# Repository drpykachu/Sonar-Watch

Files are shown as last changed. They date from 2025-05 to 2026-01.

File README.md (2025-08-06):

# Sonar Watch

### Hello all! 

### This project is inspired by something that I wanted to buy, but could not find online - so I decided to make it.

<div align="center">
  Demo
</div>

### When the button is pressed, the watch sends out a "ping" to find the location of the hour (inner radial dot) and minute (outer radial dot), thus telling the time.

<div align="center">
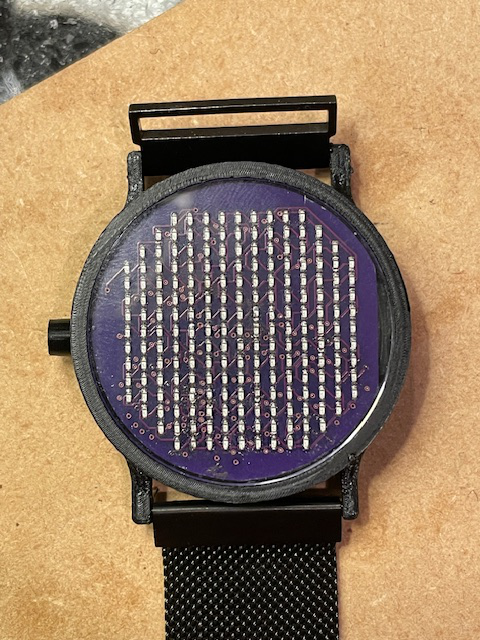
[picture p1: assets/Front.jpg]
Front
  
  <br/>
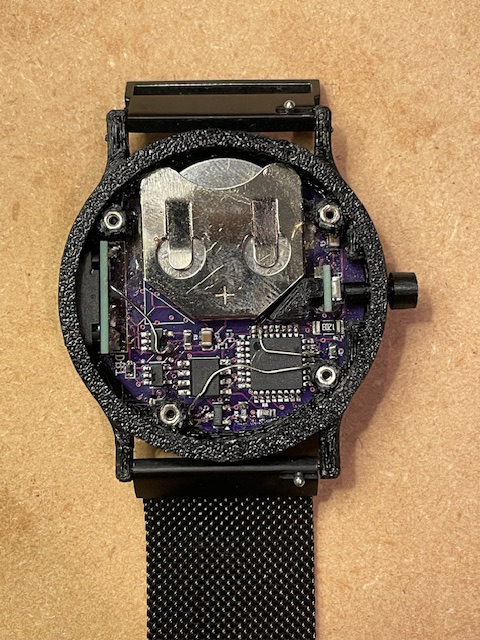
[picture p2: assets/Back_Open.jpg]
Back (open)
  
  <br/>
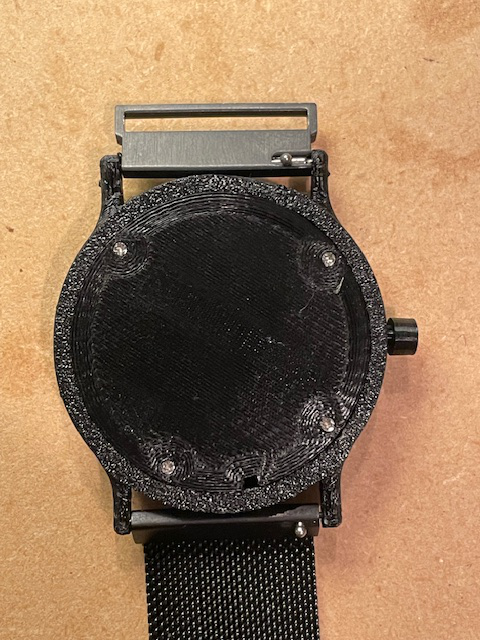
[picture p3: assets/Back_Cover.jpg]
Back (closed)
  
  <br/>
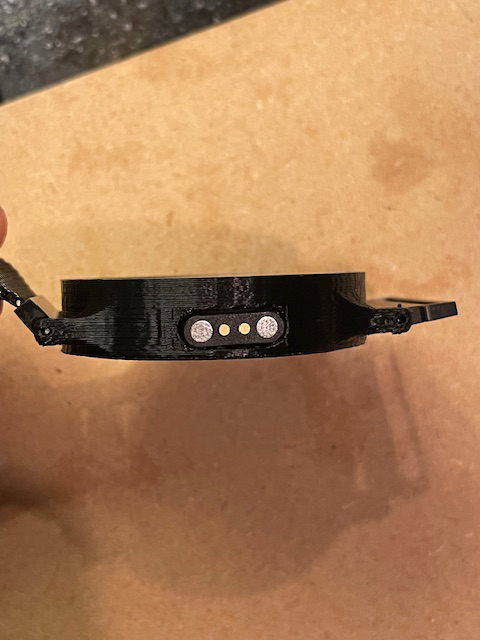
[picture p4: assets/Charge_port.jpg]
Magnetic Charging Port
  
</div>

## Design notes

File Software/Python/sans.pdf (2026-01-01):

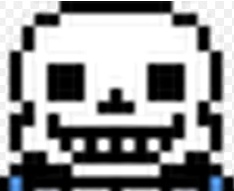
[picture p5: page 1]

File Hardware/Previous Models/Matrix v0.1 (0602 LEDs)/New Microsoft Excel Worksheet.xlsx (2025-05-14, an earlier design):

Column1 | A | B | C | D | E | F
1.1 | LOW | HIGH | INPUT | INPUT | INPUT | INPUT
1.2 | LOW | INPUT | HIGH | INPUT | INPUT | INPUT
1.3 | HIGH | INPUT | LOW | INPUT | INPUT | INPUT
1.4 | INPUT | INPUT | LOW | INPUT | HIGH | INPUT
1.5 | INPUT | INPUT | HIGH | INPUT | LOW | INPUT
2.1 | INPUT | LOW | HIGH | INPUT | INPUT | INPUT
2.2 | INPUT | HIGH | LOW | INPUT | INPUT | INPUT
2.3 | LOW | INPUT | INPUT | INPUT | HIGH | INPUT
2.4 | HIGH | INPUT | INPUT | INPUT | LOW | INPUT
2.5 | INPUT | INPUT | LOW | INPUT | INPUT | HIGH
3.1 | INPUT | INPUT | LOW | HIGH | INPUT | INPUT
3.2 | INPUT | LOW | INPUT | INPUT | HIGH | INPUT
3.3 | INPUT | HIGH | INPUT | INPUT | LOW | INPUT
3.4 | LOW | INPUT | INPUT | INPUT | INPUT | HIGH
3.5 | HIGH | INPUT | INPUT | INPUT | INPUT | LOW
4.1 | INPUT | INPUT | INPUT | LOW | HIGH | INPUT
4.2 | INPUT | INPUT | INPUT | HIGH | LOW | INPUT
4.3 | INPUT | LOW | INPUT | INPUT | INPUT | HIGH
4.4 | INPUT | HIGH | INPUT | INPUT | INPUT | LOW
4.5 | LOW | INPUT | INPUT | HIGH | INPUT | INPUT
5.1 | INPUT | INPUT | INPUT | INPUT | LOW | HIGH
5.2 | INPUT | INPUT | INPUT | LOW | INPUT | HIGH
5.3 | INPUT | INPUT | INPUT | HIGH | INPUT | LOW
5.4 | INPUT | LOW | INPUT | HIGH | INPUT | INPUT
5.5 | INPUT | HIGH | INPUT | LOW | INPUT | INPUT

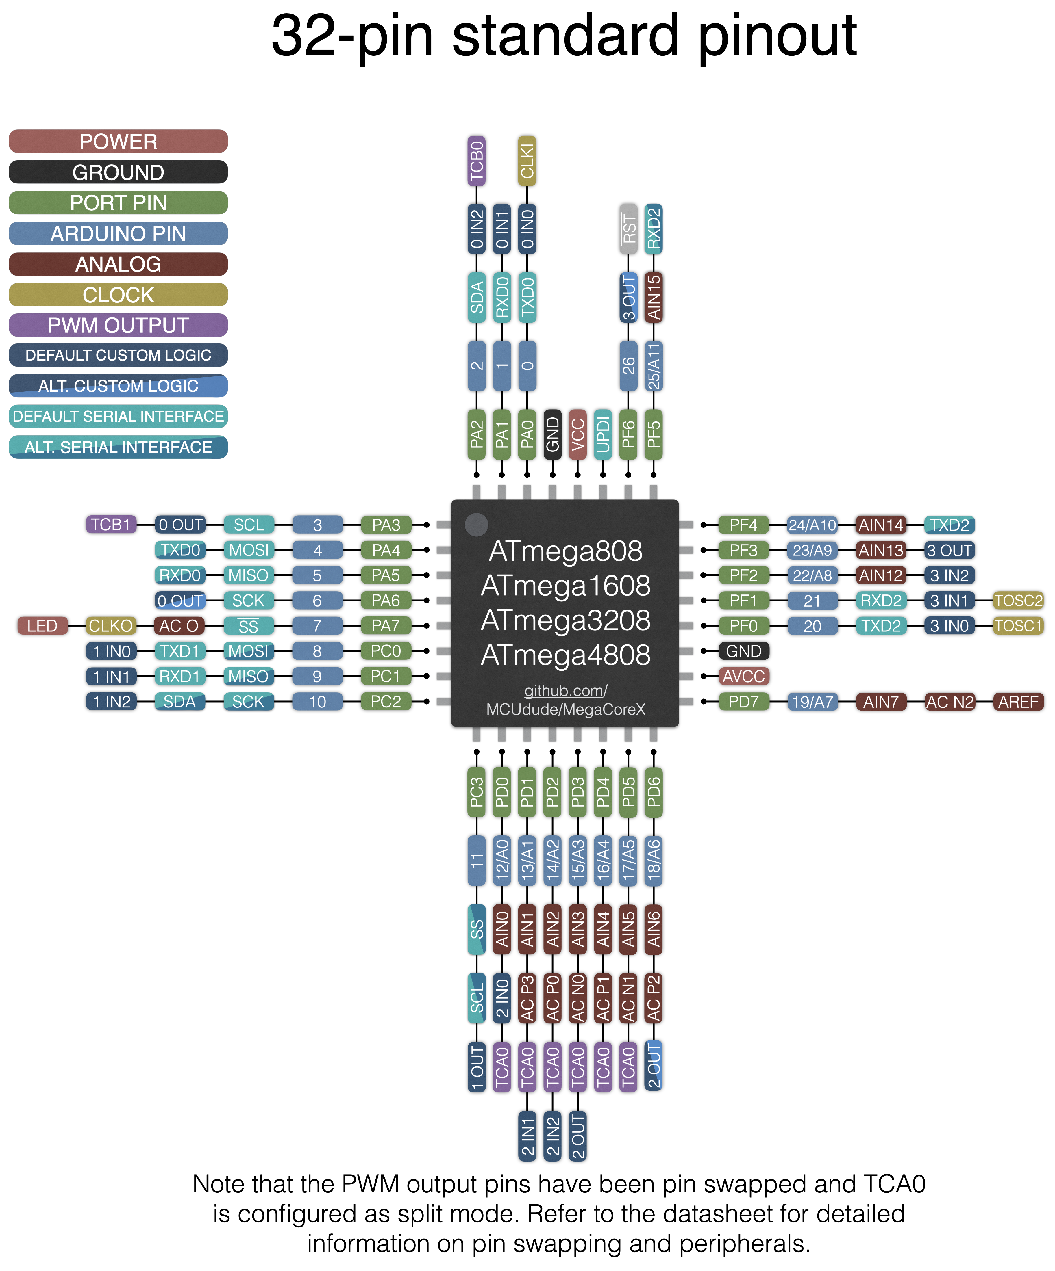
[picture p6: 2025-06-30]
Hardware/Complete v3.0/68747470733a2f2f692e696d6775722e636f6d2f32596c6d4538702e706e67.png

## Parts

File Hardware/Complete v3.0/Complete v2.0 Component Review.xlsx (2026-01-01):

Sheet: Connections
Reference: | POGO1
Component: | 2x1 Pogo Connector
Function: | USB Charging
Pin # | Pin Function | Connects to Component | At Pin | Reviewed? | Notes
1 | USB_+ | CHG1 | 4 | Yes
1 | USB_+ | DB1 | A | Yes
2 | USB_- | GNDREF | -- | Yes
3 | UPDI | 27 | 27 | Yes
4 | NC | -- | -- | Yes
Reference: | CHG1
Component: | MCP73832T-2ACI_OT
Function: | Battery Charger
Pin # | Pin Function | Connects to Component | At Pin | Reviewed? | Notes
1 | STAT | R3 | 1 | Yes
1 | STAT | U2 | PF4 | Yes
2 | VSS | GNDREF | -- | Yes
3 | VBAT | C2 | 1 | Yes
3 | VBAT | BT1 | P | Yes
3 | VBAT | U1 | 1 | Yes
3 | VBAT | R5 | 1 | Yes
4 | VDD | POGO1 | 1 | Yes
4 | VDD | DB1 | A | Yes
5 | PROG | R1 | 1 | Yes
Reference: | U1
Component: | Voltage Regulator
Function: | regualtes votlage to 3.3V
Pin # | Pin Function | Connects to Component | At Pin | Reviewed? | Notes
1 | IN | CHG1 | VBAT | Yes
1 | IN | BT1 | P | Yes
1 | IN | R5 | 1 | Yes
2 | VSS | GNDREF | -- | Yes
3 | EN | DB1 | C | Yes
3 | EN | DB2 | C | Yes
4 | NC | -- | -- | Yes
5 | OUT | C1 | 1 | Yes
5 | OUT | U3 | VBAT | Yes
5 | OUT | R7 | 2 | Yes
5 | OUT | R8 | 2 | Yes
5 | OUT | U2 | 28 | Yes
5 | OUT | U2 | 18 | Yes
5 | OUT | BB_B1 | 1 | Yes
5 | OUT | R3 | 2 | Yes
Reference: | U2
Component: | ATMEGA4808-AU
Function: | Controller
Pin # | Pin Function | Connects to Component | At Pin | Reviewed? | Notes
1 | PA3 | U3 | SCL | Yes
2 | PA4 | LED | A | Yes
3 | PA5 | LED | B | Yes
4 | PA6 | LED | C | Yes
5 | PA7 | LED | D | Yes
6 | PC0 | LED | E | Yes
7 | PC1 | LED | F | Yes
8 | PC2 | LED | G | Yes
9 | PC3 | LED | H | Yes
10 | PD0 | LED | I | Yes
11 | PD1 | LED | J | Yes
12 | PD2 | LED | K | Yes
13 | PD3 | LED | L | Yes
14 | PD4 | LED | M | Yes
15 | PD5 | LED | N | Yes
16 | PD6 | LED | O | Yes
17 | PD7 | LED | P | Yes
18 | AVDD | C1 | 1 | Yes
18 | AVDD | U3 | VBAT | Yes
18 | AVDD | R7 | 2 | Yes
18 | AVDD | R8 | 2 | Yes
18 | AVDD | U2 | 28 | Yes
18 | AVDD | BB_B1 | 1 | Yes
18 | AVDD | R3 | 2 | Yes
18 | AVDD | U1 | 5 | Yes
19 | GND | GNDREF | -- | Yes
20 | PF0 | NC | -- | Yes
21 | PF1 | NC | -- | Yes
22 | PF2 | NC | -- | Yes
23 | PF3 | U3 | VCC | Yes
24
25
26

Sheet: Parts
Index | Item | Added? | Acquired | Board Count | Purchase Amount | Unit Price | Max Price | Link
1 | GRM21BC81E106ME51K | Yes | Yes | 0 | 0 | $0.24 | $0.00 | https://www.digikey.com/en/products/detail/murata-electronics/GRM21BC81E106ME51K/10694904
2 | RN73H1JTTD5052F50 | Yes | Yes | 0 | 0 | $0.21 | $0.00 | https://www.digikey.co.nz/en/products/detail/koa-speer-electronics-inc/RN73H1JTTD5052F50/10689137
3 | MCP73832T-2ACI_OT | Yes | Yes | 1 | 15 | $0.76 | $11.40 | https://www.digikey.com/en/products/detail/microchip-technology/MCP73832T-2ACI-OT/1223142
4 | LIR2032 | Yes | Yes | 0 | 0 | $1.33 | $0.00 | https://www.amazon.com/EEMB-LIR2032-Rechargeable-Batteries-Controllers/dp/B07MHXSM8R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
5 | TPS7A0230PDBVR | Yes | Yes | 0 | 0 | $1.30 | $0.00 | https://www.digikey.com/en/products/detail/texas-instruments/TPS7A0230PDBVR/12165118
6 | BAS3010A03WE6327HTSA1 | Yes | Yes | 0 | 0 | $0.36 | $0.00 | https://www.digikey.com/en/products/detail/infineon-technologies/BAS3010A03WE6327HTSA1/1280885
8 | B3U-1100P | Yes | Yes | 0 | 0 | $0.57 | $0.00 | https://www.digikey.com/en/products/detail/omron-electronics-inc-emc-div/B3U-1100P/1534339
9 | STM32G431KBT6 (LQFP32) |  | Yes | 0 | 0 | $4.87 | $0.00 | https://estore.st.com/en/stm32g431kbt6-cpn.html
10 | RC1206FR-07120KL | Yes | Yes | 0 | 0 | $0.10 | $0.00 | https://www.digikey.com/en/products/detail/yageo/RC1206FR-07120KL/728524
11 | RMCF0603FT300K | Yes | Yes | 0 | 0 | $0.10 | $0.00 | https://www.digikey.com/en/products/detail/stackpole-electronics-inc/RMCF0603FT300K/1760826
12 | 1N4148WT | Yes | Yes | 0 | 0 | $0.10 | $0.00 | https://www.digikey.com/en/products/detail/onsemi/1N4148WT/1954014
13 | BAT-HLD-003-SMT | Yes | Yes | 1 | 15 | $0.28 | $4.20 | https://www.digikey.com/en/products/detail/te-connectivity-linx/BAT-HLD-003-SMT/14301785
14 | Pogo | Yes | Yes | 1 | 15 | $5.00 | $74.92 | https://www.amazon.com/dp/B0CSX6ZQ1H?ref_=ppx_hzsearch_conn_dt_b_fed_asin_title_1
15 | RC1005F103CS | Yes | Yes | 1 | 15 | $0.10 | $1.50 | https://www.digikey.com/en/products/detail/samsung-electro-mechanics/RC1005F103CS/3903439
16 | DS3231MZ/V+ | Yes | Yes | 1 | 3 | $11.41 | $34.23 | https://www.digikey.com/en/products/detail/analog-devices-inc-maxim-integrated/DS3231MZ-V/3133910
17 | IRLML6402TRPBF | Yes | Yes | 1 | 15 | $0.40 | $6.00 | https://www.digikey.com/en/products/detail/infineon-technologies/IRLML6402TRPBF/811437
18 | LEDS | Yes | Yes | 201 | 500 | $33.34 | $33.34 | https://www.digikey.com/en/products/detail/venkel/CTL0402FGR1T-CT/21528282
18 | RC0201FR-074K7L | Yes | Yes | 2 | 30 | $0.10 | $3.00 | https://www.digikey.com/en/products/detail/yageo/RC0201FR-074K7L/1948894
19 | ATMEGA4808-AU | Yes | Yes | 1 | 10 | $1.57 | $15.70 | https://www.digikey.com/en/products/detail/microchip-technology/ATMEGA4808-AU/10444933?gad_source=1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
20 | SI2301DS | Yes | Yes | 1 | 100 | $6.95 | $6.95 | https://www.amazon.com/dp/B08RHQGB8F?ref=ppx_yo2ov_dt_b_fed_asin_title

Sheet: Math
Programming Resistor |  |  |  |  |  | LIR2032: |  |  |  |  | MCP73832T-2ACI_OT
Item | Value | Units
R_Prog | 50.5 | kOhm
I_Reg | 19.8019802 | mA | beneath the 35mA max charge current
Capacity | 40 | mAh
time to full | 2.02 | hours
Voltage Ladder Part 1 - finding Resistances at Max charge
Item | Value | Units
Current | 0.0100 | mA |  | 4000
R_TOT | 420 | kOhms
V1 | 4.2 | V
V2 | 3 | V
GROUND | 0 | V
R1 | 120 | kOhms
R2 | 300 | kOhms
Voltage Ladder Part 2 - Finding voltages at Min charge
Item | Value | Units
Current | 0.007142857143 | mA
R_TOT | 420 | kOhms
R1 | 120 | kOhms
R2 | 300 | kOhms
V1 | 3 | V
V2 | 2.142857143 | V
GROUND | 0 | V
Voltage Ladder Part 3 - Finding voltages at random charge
Item | Value | Units
Current | 0.007380952381 | mA
R_TOT | 420 | kOhms
R1 | 120 | kOhms
R2 | 300 | kOhms |  |  |  |  | Voltage - capacity chart
V1 | 3.1 | V
GROUND | 0 | V
V2 | 2.214285714 | V
Voltage Ladder Part 4 - Finding minum voltage to portect battery
Item | Value | Units
Current | 0.007619047619 | mA |  |  | Raw data |  |  | Needed data
R_TOT | 420 | kOhms |  |  | V | Cap |  | adjsuted volts | Scaled volts | inverse charge
R1 | 120 | kOhms |  |  | 4.14 | 0.29 |  | 4.2 | 3.000 | 100
R2 | 300 | kOhms |  |  | 4.10 | 2.43 |  | 4.14 | 2.960 | 99
V1 | 3.2 | V |  |  | 4.05 | 4.56 |  | 4.10 | 2.928 | 97.57338873
GROUND | 0 | V |  |  | 4.02 | 7.01 |  | 4.05 | 2.896 | 95.43544664
V2 | 2.285714286 | V |  |  | 3.97 | 10.52 |  | 4.02 | 2.873 | 92.9900383
 |  |  |  |  | 3.93 | 13.73 |  | 3.97 | 2.835 | 89.47543515
 |  |  |  |  | 3.86 | 17.86 |  | 3.93 | 2.806 | 86.26561294
 |  |  |  |  | 3.83 | 21.68 |  | 3.86 | 2.759 | 82.14010525
 |  |  |  |  | 3.79 | 26.88 |  | 3.83 | 2.733 | 78.31758831
 |  |  |  |  | 3.75 | 31.93 |  | 3.79 | 2.710 | 73.11706766
 |  |  |  |  | 3.73 | 36.82 |  | 3.75 | 2.677 | 68.07095145
 |  |  |  |  | 3.71 | 42.64 |  | 3.73 | 2.663 | 63.17521175
 |  |  |  |  | 3.70 | 49.37 |  | 3.71 | 2.648 | 57.36110127
 |  |  |  |  | 3.67 | 57.18 |  | 3.70 | 2.640 | 50.62772492
 |  |  |  |  | 3.67 | 64.52 |  | 3.67 | 2.620 | 42.8247062
 |  |  |  |  | 3.66 | 71.56 |  | 3.67 | 2.620 | 35.47774003
 |  |  |  |  | 3.65 | 79.67 |  | 3.66 | 2.617 | 28.43734499
 |  |  |  |  | 3.61 | 84.87 |  | 3.65 | 2.608 | 20.32641248
 |  |  |  |  | 3.57 | 89.00 |  | 3.61 | 2.579 | 15.12678693
 |  |  |  |  | 3.52 | 93.74 |  | 3.57 | 2.547 | 10.9990415
 |  |  |  |  | 3.39 | 97.09 |  | 3.52 | 2.512 | 6.259496433
 |  |  |  |  | 3.27 | 99.99 |  | 3.39 | 2.422 | 2.906010957
 |  |  |  |  | 3.13 | 102.73 |  | 3.20 | 2.286 | 0.01126331925
 |  |  |  |  | 2.99 | 105.16

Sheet: LED_Pins
Index | 0 | 1 | 2 | 3 | 4 | 5 | 6 | 7 | 8 | 9 | 10 | 11 | 12 | 13 | 14 | 15
Pin
 | A | B | C | D | E | F | G | H | I | J | K | L | M | N | O | P
LED\NET | 1 | 2 | 3 | 4 | 5 | 6 | 7 | 8 | 9 | 10 | 11 | 12 | 13 | 14 | 15 | 16
D1 | LOW |  |  |  | HIGH
D2 | HIGH |  |  |  | LOW
D3 |  |  |  |  | LOW |  | HIGH
D4 |  |  |  |  | HIGH |  | LOW
D5 |  |  |  |  |  |  | LOW |  | HIGH
D6 |  |  |  |  |  |  | HIGH |  | LOW
D7 |  |  |  |  |  |  |  |  | LOW |  | HIGH
D8 |  |  |  |  |  |  |  |  | HIGH |  | LOW
D9 |  |  |  |  |  |  |  |  |  |  | LOW |  | HIGH
D10 |  | LOW |  |  | HIGH
D11 |  | HIGH |  |  | LOW
D12 | LOW |  |  |  |  |  | HIGH
D13 | HIGH |  |  |  |  |  | LOW
D14 |  |  |  |  | LOW |  |  |  | HIGH
D15 |  |  |  |  | HIGH |  |  |  | LOW
D16 |  |  |  |  |  |  | LOW |  |  |  | HIGH
D17 |  |  |  |  |  |  | HIGH |  |  |  | LOW
D18 |  |  |  |  |  |  |  |  | LOW |  |  |  | HIGH
D19 |  |  |  |  |  |  |  |  | HIGH |  |  |  | LOW
D20 |  |  |  |  |  |  |  |  |  |  | LOW |  |  | HIGH
D21 |  |  | LOW |  | HIGH
D22 |  |  | HIGH |  | LOW
D23 |  | LOW |  |  |  |  | HIGH
D24 |  | HIGH |  |  |  |  | LOW
D25 | LOW |  |  |  |  |  |  |  | HIGH
D26 | HIGH |  |  |  |  |  |  |  | LOW
D27 |  |  |  |  | LOW |  |  |  |  |  | HIGH
D28 |  |  |  |  | HIGH |  |  |  |  |  | LOW
D29 |  |  |  |  |  |  | LOW |  |  |  |  |  | HIGH
D30 |  |  |  |  |  |  | HIGH |  |  |  |  |  | LOW
D31 |  |  |  |  |  |  |  |  | LOW |  |  |  |  | HIGH
D32 |  |  |  |  |  |  |  |  | HIGH |  |  |  |  | LOW
D33 |  |  |  |  |  |  |  |  |  |  | LOW |  |  |  | HIGH
D34 |  |  |  | LOW | HIGH
D35 |  |  |  | HIGH | LOW
D36 |  |  | LOW |  |  |  | HIGH
D37 |  |  | HIGH |  |  |  | LOW
D38 |  | LOW |  |  |  |  |  |  | HIGH
D39 |  | HIGH |  |  |  |  |  |  | LOW
D40 | LOW |  |  |  |  |  |  |  |  |  | HIGH
D41 | HIGH |  |  |  |  |  |  |  |  |  | LOW
D42 |  |  |  |  | LOW |  |  |  |  |  |  |  | HIGH
D43 |  |  |  |  | HIGH |  |  |  |  |  |  |  | LOW
D44 |  |  |  |  |  |  | LOW |  |  |  |  |  |  | HIGH
D45 |  |  |  |  |  |  | HIGH |  |  |  |  |  |  | LOW
D46 |  |  |  |  |  |  |  |  | LOW |  |  |  |  |  | HIGH
D47 |  |  |  |  |  |  |  |  | HIGH |  |  |  |  |  | LOW
D48 |  |  |  |  |  |  |  |  |  |  | LOW |  |  |  |  | HIGH
D49 |  |  |  |  | LOW | HIGH
D50 |  |  |  | LOW |  |  | HIGH
D51 |  |  |  | HIGH |  |  | LOW
D52 |  |  | LOW |  |  |  |  |  | HIGH
D53 |  |  | HIGH |  |  |  |  |  | LOW
D54 |  | LOW |  |  |  |  |  |  |  |  | HIGH
D55 |  | HIGH |  |  |  |  |  |  |  |  | LOW
D56 | LOW |  |  |  |  |  |  |  |  |  |  |  | HIGH
D57 | HIGH |  |  |  |  |  |  |  |  |  |  |  | LOW
D58 |  |  |  |  | LOW |  |  |  |  |  |  |  |  | HIGH
D59 |  |  |  |  | HIGH |  |  |  |  |  |  |  |  | LOW
D60 |  |  |  |  |  |  | LOW |  |  |  |  |  |  |  | HIGH
D61 |  |  |  |  |  |  | HIGH |  |  |  |  |  |  |  | LOW
D62 |  |  |  |  |  |  |  |  | LOW |  |  |  |  |  |  | HIGH
D63 |  |  |  |  |  |  |  |  | HIGH |  |  |  |  |  |  | LOW
D64 |  |  |  |  |  | LOW | HIGH
D65 |  |  |  |  |  | HIGH | LOW
D66 |  |  |  | LOW |  |  |  |  | HIGH
D67 |  |  |  | HIGH |  |  |  |  | LOW
D68 |  |  | LOW |  |  |  |  |  |  |  | HIGH
D69 |  |  | HIGH |  |  |  |  |  |  |  | LOW
D70 |  | LOW |  |  |  |  |  |  |  |  |  |  | HIGH
D71 |  | HIGH |  |  |  |  |  |  |  |  |  |  | LOW
D72 | LOW |  |  |  |  |  |  |  |  |  |  |  |  | HIGH
D73 | HIGH |  |  |  |  |  |  |  |  |  |  |  |  | LOW
D74 |  |  |  |  | LOW |  |  |  |  |  |  |  |  |  | HIGH
D75 |  |  |  |  | HIGH |  |  |  |  |  |  |  |  |  | LOW
D76 |  |  |  |  |  |  | LOW |  |  |  |  |  |  |  |  | HIGH
D77 |  |  |  |  |  |  | HIGH |  |  |  |  |  |  |  |  | LOW
D78 |  |  |  |  |  |  |  |  | LOW |  |  | HIGH
D79 |  |  |  |  |  |  | LOW | HIGH
D80 |  |  |  |  |  | LOW |  |  | HIGH
D81 |  |  |  |  |  | HIGH |  |  | LOW
D82 |  |  |  | LOW |  |  |  |  |  |  | HIGH
D83 |  |  |  | HIGH |  |  |  |  |  |  | LOW
D84 |  |  | LOW |  |  |  |  |  |  |  |  |  | HIGH
D85 |  |  | HIGH |  |  |  |  |  |  |  |  |  | LOW
D86 |  | LOW |  |  |  |  |  |  |  |  |  |  |  | HIGH
D87 |  | HIGH |  |  |  |  |  |  |  |  |  |  |  | LOW
D88 | LOW |  |  |  |  |  |  |  |  |  |  |  |  |  | HIGH
D89 | HIGH |  |  |  |  |  |  |  |  |  |  |  |  |  | LOW
D90 |  |  |  |  | LOW |  |  |  |  |  |  |  |  |  |  | HIGH
D91 |  |  |  |  | HIGH |  |  |  |  |  |  |  |  |  |  | LOW
D92 |  |  |  |  |  |  | LOW |  |  |  |  | HIGH
D93 |  |  |  |  |  |  | HIGH |  |  |  |  | LOW
D94 |  |  |  |  |  |  |  | LOW | HIGH
D95 |  |  |  |  |  |  |  | HIGH | LOW
D96 |  |  |  |  |  | LOW |  |  |  |  | HIGH
D97 |  |  |  |  |  | HIGH |  |  |  |  | LOW
D98 |  |  |  | LOW |  |  |  |  |  |  |  |  | HIGH
D99 |  |  |  | HIGH |  |  |  |  |  |  |  |  | LOW
D100 |  |  | LOW |  |  |  |  |  |  |  |  |  |  | HIGH
D101 |  |  | HIGH |  |  |  |  |  |  |  |  |  |  | LOW
D102 |  | LOW |  |  |  |  |  |  |  |  |  |  |  |  | HIGH
D103 |  | HIGH |  |  |  |  |  |  |  |  |  |  |  |  | LOW
D104 | LOW |  |  |  |  |  |  |  |  |  |  |  |  |  |  | HIGH
D105 | HIGH |  |  |  |  |  |  |  |  |  |  |  |  |  |  | LOW
D106 |  |  |  |  | LOW |  |  |  |  |  |  | HIGH
D107 |  |  |  |  | HIGH |  |  |  |  |  |  | LOW
D108 |  |  |  |  |  |  | LOW |  |  | HIGH
D109 |  |  |  |  |  |  |  |  | LOW | HIGH
D110 |  |  |  |  |  |  |  | LOW |  |  | HIGH
D111 |  |  |  |  |  |  |  | HIGH |  |  | LOW
D112 |  |  |  |  |  | LOW |  |  |  |  |  |  | HIGH
D113 |  |  |  |  |  | HIGH |  |  |  |  |  |  | LOW
D114 |  |  |  | LOW |  |  |  |  |  |  |  |  |  | HIGH
D115 |  |  |  | HIGH |  |  |  |  |  |  |  |  |  | LOW
D116 |  |  | LOW |  |  |  |  |  |  |  |  |  |  |  | HIGH
D117 |  |  | HIGH |  |  |  |  |  |  |  |  |  |  |  | LOW
D118 |  | LOW |  |  |  |  |  |  |  |  |  |  |  |  |  | HIGH
D119 |  | HIGH |  |  |  |  |  |  |  |  |  |  |  |  |  | LOW
D120 | LOW |  |  |  |  |  |  |  |  |  |  | HIGH
D121 | HIGH |  |  |  |  |  |  |  |  |  |  | LOW
D122 |  |  |  |  | LOW |  |  |  |  | HIGH
D123 |  |  |  |  | HIGH |  |  |  |  | LOW
D124 |  |  |  |  |  |  |  |  |  | LOW | HIGH
D125 |  |  |  |  |  |  |  |  |  | HIGH | LOW
D126 |  |  |  |  |  |  |  | LOW |  |  |  |  | HIGH
D127 |  |  |  |  |  |  |  | HIGH |  |  |  |  | LOW
D128 |  |  |  |  |  | LOW |  |  |  |  |  |  |  | HIGH
D129 |  |  |  |  |  | HIGH |  |  |  |  |  |  |  | LOW
D130 |  |  |  | LOW |  |  |  |  |  |  |  |  |  |  | HIGH
D131 |  |  |  | HIGH |  |  |  |  |  |  |  |  |  |  | LOW
D132 |  |  | LOW |  |  |  |  |  |  |  |  |  |  |  |  | HIGH
D133 |  |  | HIGH |  |  |  |  |  |  |  |  |  |  |  |  | LOW
D134 |  | LOW |  |  |  |  |  |  |  |  |  | HIGH
D135 |  | HIGH |  |  |  |  |  |  |  |  |  | LOW
D136 | LOW |  |  |  |  |  |  |  |  | HIGH
D137 | HIGH |  |  |  |  |  |  |  |  | LOW
D138 |  |  |  |  | LOW |  |  | HIGH
D139 |  |  |  |  |  |  |  |  |  |  | LOW | HIGH
D140 |  |  |  |  |  |  |  |  |  | LOW |  |  | HIGH
D141 |  |  |  |  |  |  |  |  |  | HIGH |  |  | LOW
D142 |  |  |  |  |  |  |  | LOW |  |  |  |  |  | HIGH
D143 |  |  |  |  |  |  |  | HIGH |  |  |  |  |  | LOW
D144 |  |  |  |  |  | LOW |  |  |  |  |  |  |  |  | HIGH
D145 |  |  |  |  |  | HIGH |  |  |  |  |  |  |  |  | LOW
D146 |  |  |  | LOW |  |  |  |  |  |  |  |  |  |  |  | HIGH
D147 |  |  |  | HIGH |  |  |  |  |  |  |  |  |  |  |  | LOW
D148 |  |  | LOW |  |  |  |  |  |  |  |  | HIGH
D149 |  |  | HIGH |  |  |  |  |  |  |  |  | LOW
D150 |  | LOW |  |  |  |  |  |  |  | HIGH
D151 |  | HIGH |  |  |  |  |  |  |  | LOW
D152 | LOW |  |  |  |  |  |  | HIGH
D153 | HIGH |  |  |  |  |  |  | LOW
D154 |  |  |  |  |  |  |  |  |  |  |  | LOW | HIGH
D155 |  |  |  |  |  |  |  |  |  |  |  | HIGH | LOW
D156 |  |  |  |  |  |  |  |  |  | LOW |  |  |  | HIGH
D157 |  |  |  |  |  |  |  |  |  | HIGH |  |  |  | LOW
D158 |  |  |  |  |  |  |  | LOW |  |  |  |  |  |  | HIGH
D159 |  |  |  |  |  |  |  | HIGH |  |  |  |  |  |  | LOW
D160 |  |  |  |  |  | LOW |  |  |  |  |  |  |  |  |  | HIGH
D161 |  |  |  |  |  | HIGH |  |  |  |  |  |  |  |  |  | LOW
D162 |  |  |  | LOW |  |  |  |  |  |  |  | HIGH
D163 |  |  |  | HIGH |  |  |  |  |  |  |  | LOW
D164 |  |  | LOW |  |  |  |  |  |  | HIGH
D165 |  |  | HIGH |  |  |  |  |  |  | LOW
D166 |  | LOW |  |  |  |  |  | HIGH
D167 |  | HIGH |  |  |  |  |  | LOW
D168 | LOW |  |  |  |  | HIGH
D169 |  |  |  |  |  |  |  |  |  |  |  | LOW |  | HIGH
D170 |  |  |  |  |  |  |  |  |  |  |  | HIGH |  | LOW
D171 |  |  |  |  |  |  |  |  |  | LOW |  |  |  |  | HIGH
D172 |  |  |  |  |  |  |  |  |  | HIGH |  |  |  |  | LOW
D173 |  |  |  |  |  |  |  | LOW |  |  |  |  |  |  |  | HIGH
D174 |  |  |  |  |  |  |  | HIGH |  |  |  |  |  |  |  | LOW
D175 |  |  |  |  |  | LOW |  |  |  |  |  | HIGH
D176 |  |  |  |  |  | HIGH |  |  |  |  |  | LOW
D177 |  |  |  | LOW |  |  |  |  |  | HIGH
D178 |  |  |  | HIGH |  |  |  |  |  | LOW
D179 |  |  | LOW |  |  |  |  | HIGH
D180 |  |  | HIGH |  |  |  |  | LOW
D181 |  | LOW |  |  |  | HIGH
D182 |  |  |  |  |  |  |  |  |  |  |  | LOW |  |  | HIGH
D183 |  |  |  |  |  |  |  |  |  |  |  | HIGH |  |  | LOW
D184 |  |  |  |  |  |  |  |  |  | LOW |  |  |  |  |  | HIGH
D185 |  |  |  |  |  |  |  |  |  | HIGH |  |  |  |  |  | LOW
D186 |  |  |  |  |  |  |  | LOW |  |  |  | HIGH
D187 |  |  |  |  |  |  |  | HIGH |  |  |  | LOW
D188 |  |  |  |  |  | LOW |  |  |  | HIGH
D189 |  |  |  |  |  | HIGH |  |  |  | LOW
D190 |  |  |  | LOW |  |  |  | HIGH
D191 |  |  |  | HIGH |  |  |  | LOW
D192 |  |  | LOW |  |  | HIGH
D193 |  |  |  |  |  |  |  |  |  |  |  | LOW |  |  |  | HIGH
D194 |  |  |  |  |  |  |  |  |  |  |  | HIGH |  |  |  | LOW
D195 |  |  |  |  |  |  |  |  |  | LOW |  | HIGH
D196 |  |  |  |  |  |  |  |  |  | HIGH |  | LOW
D197 |  |  |  |  |  |  |  | LOW |  | HIGH
D198 |  |  |  |  |  |  |  | HIGH |  | LOW
D199 |  |  |  |  |  | LOW |  | HIGH
D200 |  |  |  |  |  | HIGH |  | LOW
D201 |  |  |  | LOW |  | HIGH
LOW | 12 | 12 | 12 | 12 | 15 | 10 | 15 | 13 | 15 | 13 | 15 | 13 | 11 | 11 | 11 | 11
HIGH | 11 | 11 | 11 | 11 | 13 | 15 | 13 | 15 | 13 | 15 | 10 | 15 | 12 | 12 | 12 | 12

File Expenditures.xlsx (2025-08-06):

Source | Order Date | Cost | Items | Purpose
PCBWAY | 2025-04-09 | $27.16 | 5x5 board | Testing
Amazon | 2025-04-15 | $39.71 | Hot Plate | Tool
Ebay | 2025-04-22 | $14.09 | LEDS | Testing
Ebay | 2025-04-22 | $30.02 | LEDS | Final
OSH Stencils | 2025-04-27 | $26.22 | Stencil 1 | Testing
STM | 2025-04-29 | $34.24 | Nucleo board | None
SUPPLIER DIRECT | 2025-04-29 | $34.24 | shipping | Shipping
Amazon | 2025-05-01 | $41.90 | Glasses and solder tips | Tool
SUPPLIER DIRECT | 2025-05-05 | $21.50 | shipping | Shipping
STM | 2025-05-06 | $21.50 | STM32 chips | None
Amazon | 2025-05-07 | $6.06 | Tweezers | Tool
OSH Park | 2025-05-08 | $25.65 | Fullgrid board | Testing
Amazon | 2025-05-10 | $11.02 | Pogo Pins | Final
Amazon | 2025-05-11 | $7.70 | Connectors | Testing
Amazon | 2025-05-24 | $14.67 | Batteries | Final
Digikey | 2025-05-24 | $87.11 | Parts | Final
PCBWAY | 2025-05-27 | $41.21 | STM board | None
DHL | 2025-05-30 | $26.85 | Shipping | Shipping
Amazon | 2025-06-03 | $9.42 | STM programmer | None
Amazon | 2025-06-04 | $9.42 | STM programmer | None
Digikey | 2025-06-09 | $30.56 | Parts | Final
Amazon | 2025-06-21 | $11.68 | DS3231 breakout | None
Amazon | 2025-06-22 | $11.68 | DS3231 breakout | Testing
Digikey | 2025-06-29 | $111.66 | Parts | Final
PCBWAY | 2025-06-30 | $163.63 | Final board | None
Amazon | 2025-07-03 | $27.01 | Watch glass and pogo pins | Final
Ebay | 2025-07-07 | $43.16 | LEDS | Final
OSH Stencils | 2025-07-08 | $29.69 | Stencil 2 | Final
OSH Park | 2025-07-08 | $47.70 | Final board | Final
Adadfruit | 2025-07-10 | $39.17 | UPDI programmers, LQFP breakout boards, pin headers | Final
 | Item | Amount | Percent
 | PCBWAY | $232.00 | 22.18758069%
 | Amazon | $190.27 | 18.19668525%
 | Ebay | $87.27 | 8.346164513%
 | OSH Stencils | $55.91 | 5.347015675%
 | STM | $55.74 | 5.330757534%
 | SUPPLIER DIRECT | $55.74 | 5.330757534%
 | OSH Park | $73.35 | 7.014909672%
 | Digikey | $229.33 | 21.93223224%
 | DHL | $26.85 | 2.567829921%
 | Adadfruit | $39.17 | 3.746066964%
 | Total | $1045.63 | 100%
 | Item | Amount | Percent
 | Testing | $112.50 | 10.75906391%
 | Tool | $87.67 | 8.384418963%
 | None | $291.10 | 27.8396756% |  | Final | $471.77 | 45.11825407%
 | Shipping | $82.59 | 7.898587454%
 | Final - Parts | $440.32 | 42.11037046%
 | Final - Complete | $31.45 | 3.007883604%
 | Total | $1045.63 | 100%

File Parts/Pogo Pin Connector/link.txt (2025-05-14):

https://www.amazon.com/dp/B0CSX6ZQ1H?ref=ppx_yo2ov_dt_b_fed_asin_title&th=1

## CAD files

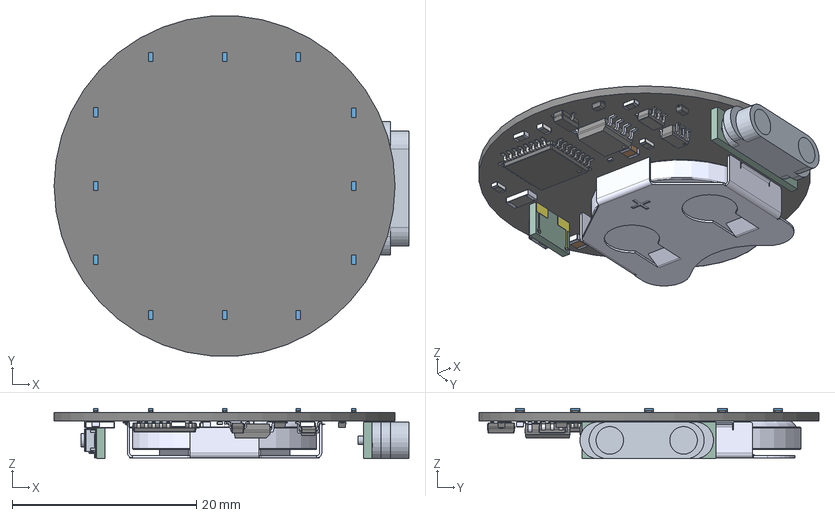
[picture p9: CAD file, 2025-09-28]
Hardware/Complete v3.0/Complete v3.0 3D models/STEP/Complete v3.0.step
38.5 x 36.9 x 5.48 mm
Contact x 96
Linse x 108
Button_Breakout_copper
Button_Breakout_pad
Button_Breakout_via
Button_Breakout_silkscreen
Button_Breakout_PCB
B3U-1100P
SOT-23
D_SOD-523 x 2
MCP73832T-2ACI_OT
POGO2_Female
Pogo_Breakout_copper
Pogo_Breakout_via
Pogo_Breakout_PCB
RN73H1JTTD5052F50 x 3
BAT-HLD-003-SMT_CUT
LIR2032
RMCF0603FT300K x 2
GRM21BC81E106ME51K x 2
RC0201FR-074K7L x 2
RC1206FR-07120KL
DS3231MZ_
TQFP-32_7x7mm_P0.8mm
BODY-SOT
LEAD-SOT x 5
LEAD-DUMMY
Complete v3.0_PCB

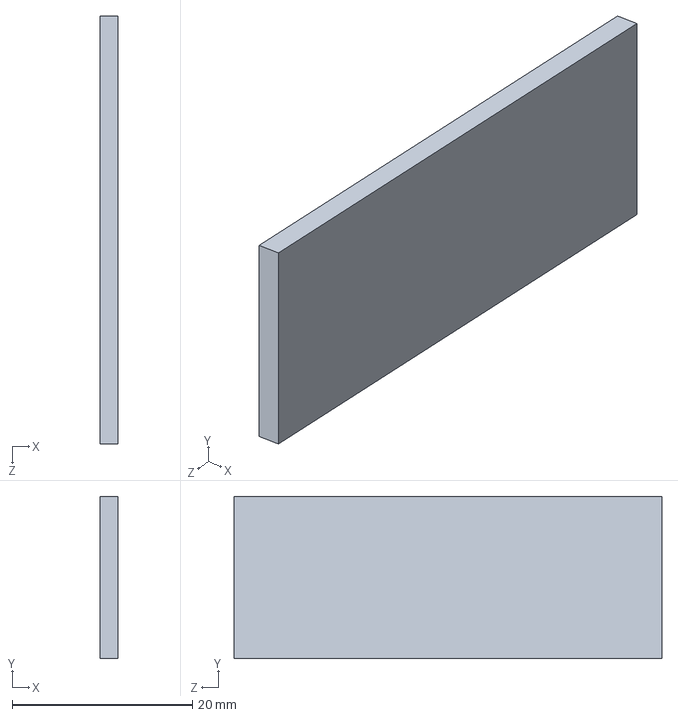
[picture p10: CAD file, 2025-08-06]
Hardware/Charger v1.0/Case_Cap.SLDPRT
2.00 x 18.0 x 47.5 mm

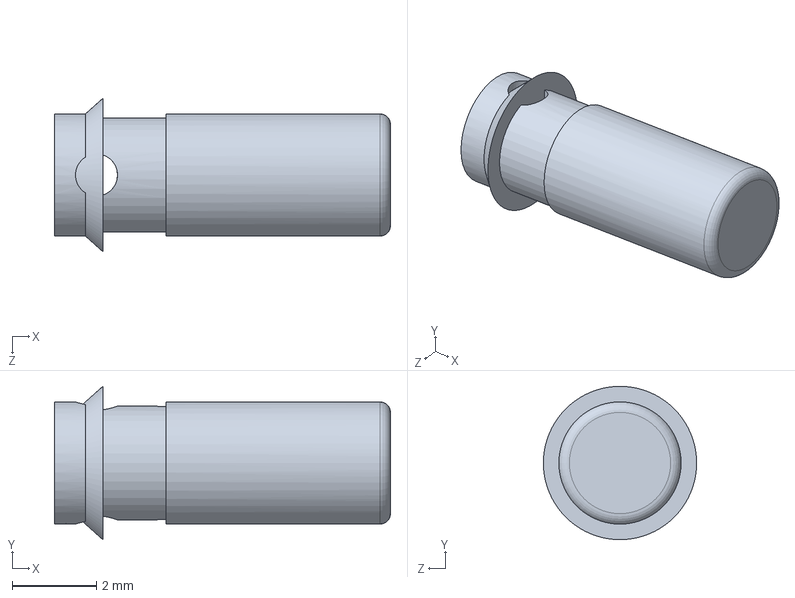
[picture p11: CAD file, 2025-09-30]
Hardware/Complete v3.0/Complete v3.0 3D models/SLDPRT/PushPin_inner.SLDPRT
8.00 x 3.65 x 3.65 mm

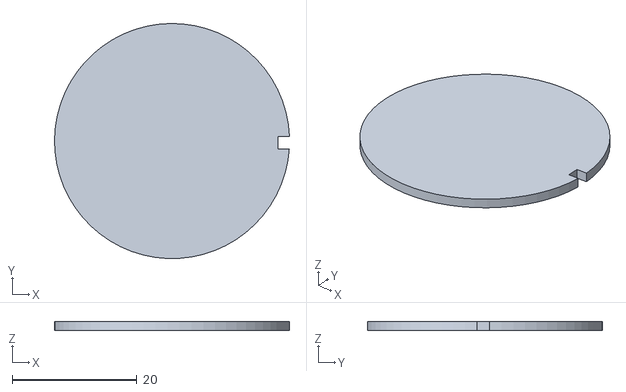
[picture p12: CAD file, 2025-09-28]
Hardware/Complete v3.0/Complete v3.0 3D models/To Print/Back.STL
37.6 x 37.6 x 1.50

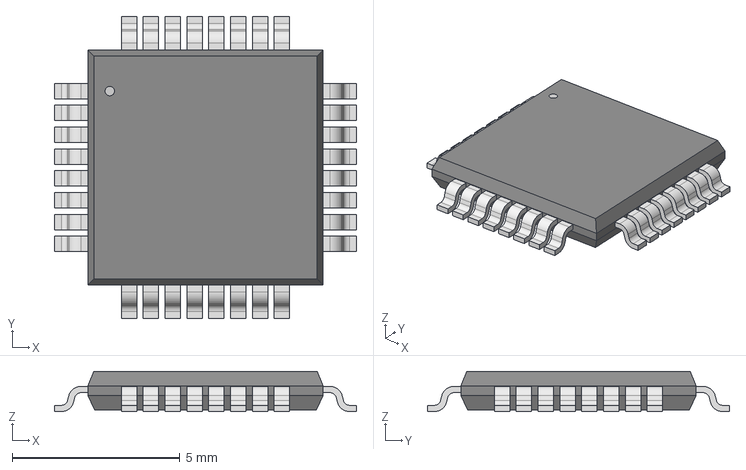
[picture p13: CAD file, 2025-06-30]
Parts/ATMEGA4808-AU/ATMEGA4808-AU.step
8.99 x 8.99 x 1.20 mm

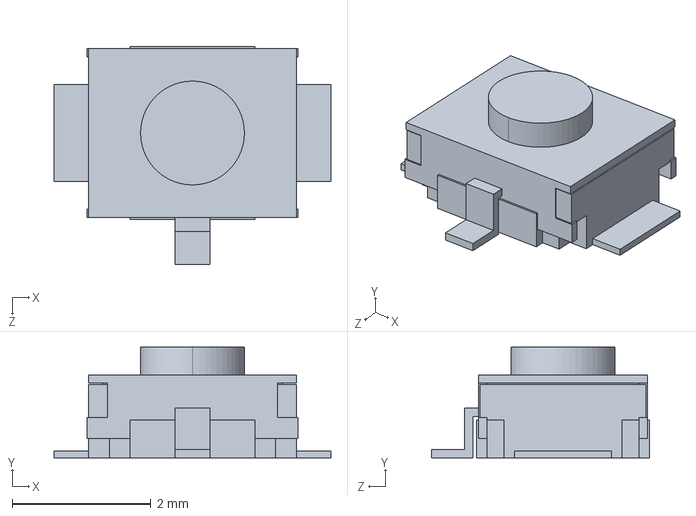
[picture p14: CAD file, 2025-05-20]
Parts/B3U_1100P/B3U-1100P.step
4.00 x 1.60 x 3.15 mm

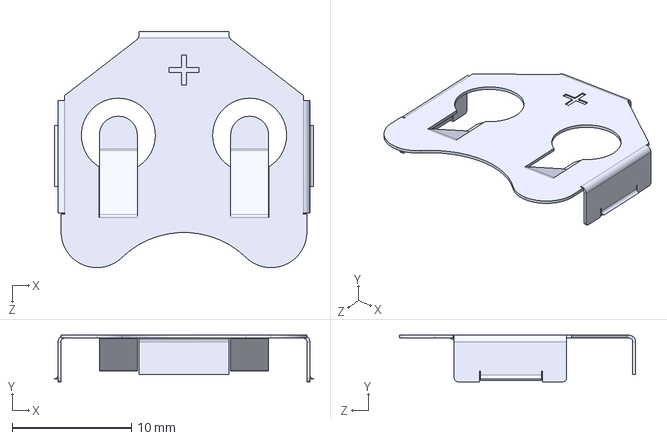
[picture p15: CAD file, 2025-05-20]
Parts/BAT-HLD-003-SMT/BAT-HLD-003-SMT_CUT.step
21.7 x 3.90 x 19.8 mm

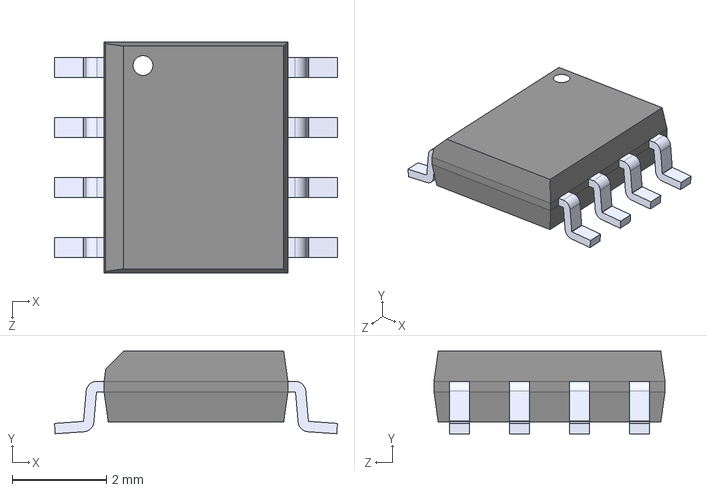
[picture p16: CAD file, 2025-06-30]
Parts/DS3231MZ/DS3231MZ_.STEP
6.00 x 1.75 x 4.90 mm

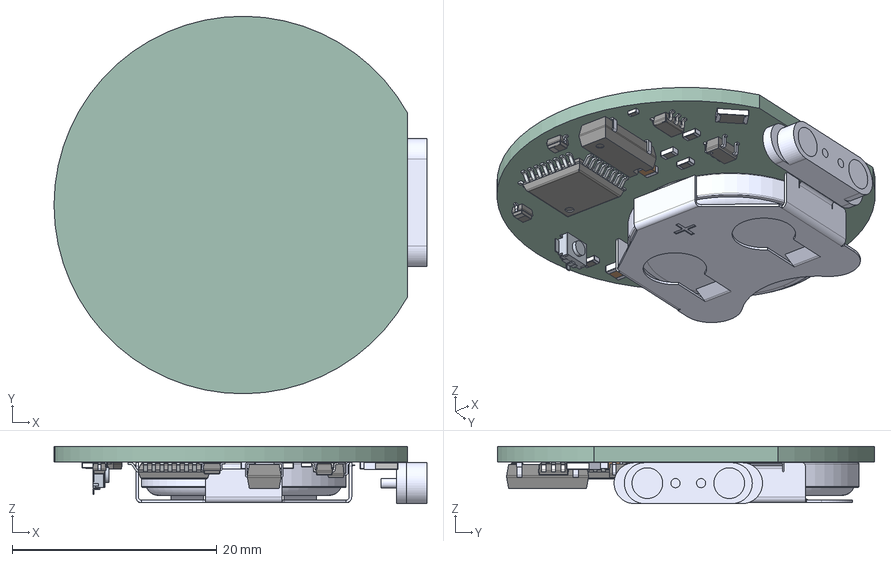
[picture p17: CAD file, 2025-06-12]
Parts/Glass/v0.4.step
36.4 x 36.9 x 5.59 mm
RN73H1JTTD5052F50 x 3
GRM21BC81E106ME51K x 3
B3U-1100P
RC1206FR-07120KL
PinsArrayLR
PinsArrayTB
POGO2_Female
MC-306_32.7680K-E0_PURE_SN
RMCF0603FT300K
BAS3010A03WE6327HTSA1 x 2
BODY-SOT
LEAD-SOT x 5
LEAD-DUMMY
LIR2032
BAT-HLD-003-SMT_CUT
MCP73832T-2ACI_OT
RC1005F103CS
D_SOD-523
Complete_PCB

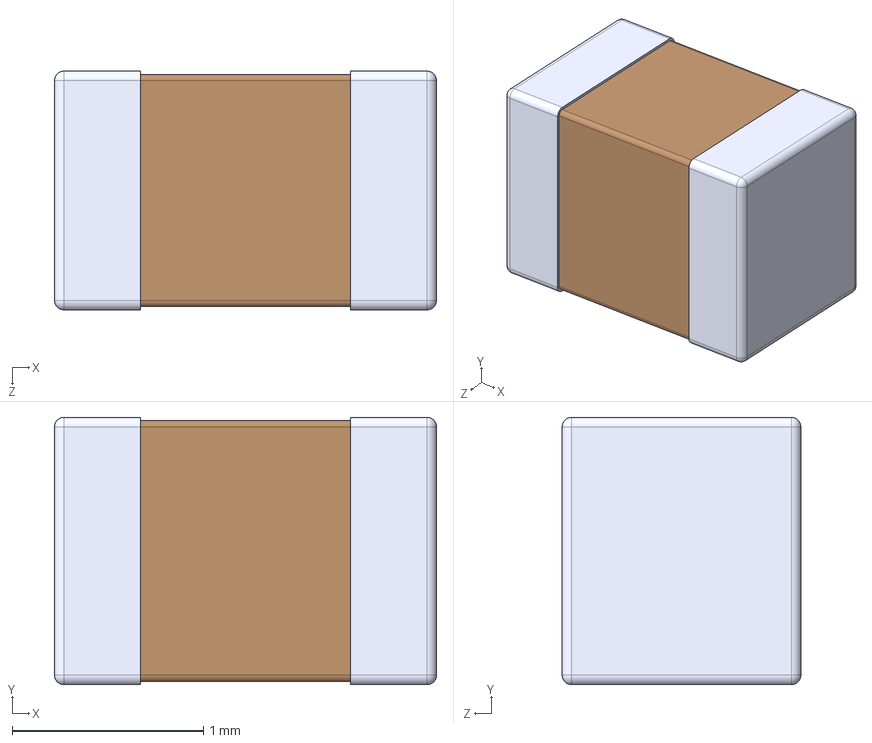
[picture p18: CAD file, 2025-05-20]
Parts/GRM21BC81E106ME51K/GRM21BC81E106ME51K.step
2.00 x 1.40 x 1.25 mm

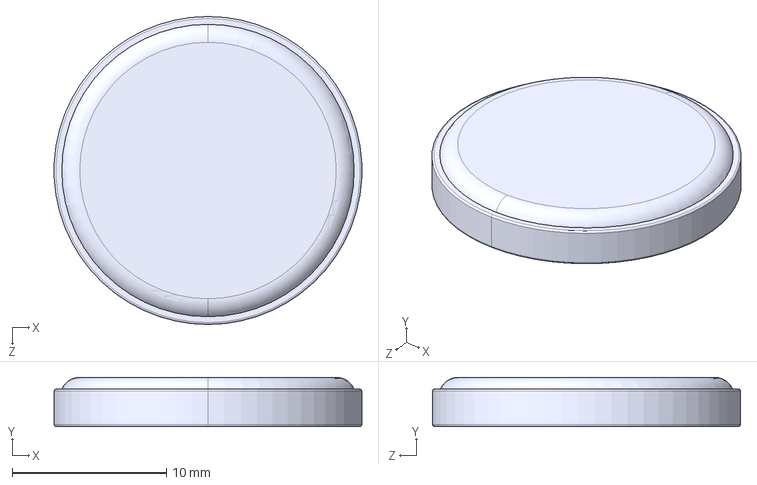
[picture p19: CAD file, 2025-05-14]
Parts/LIR2032/LIR2032.STEP
20.0 x 3.20 x 20.0 mm

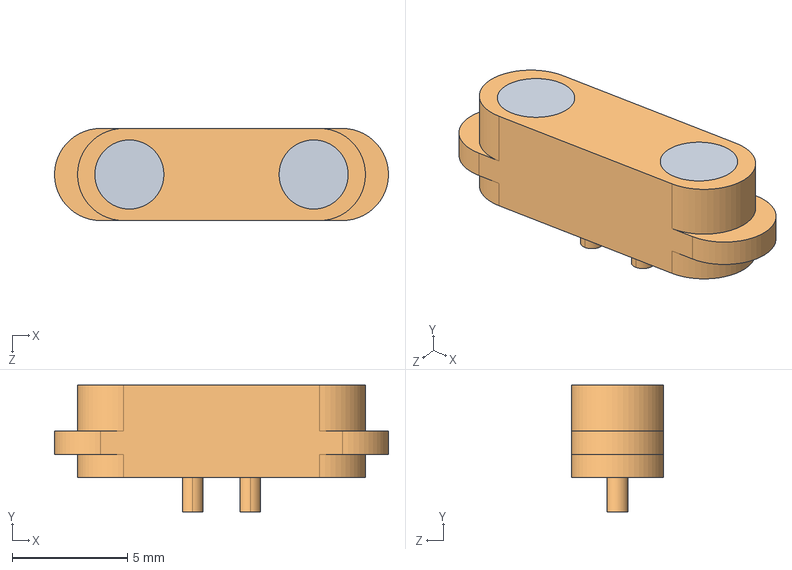
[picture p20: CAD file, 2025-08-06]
Parts/Pogo Pin Connector/POGO2_Female.STEP
14.5 x 5.50 x 4.00 mm

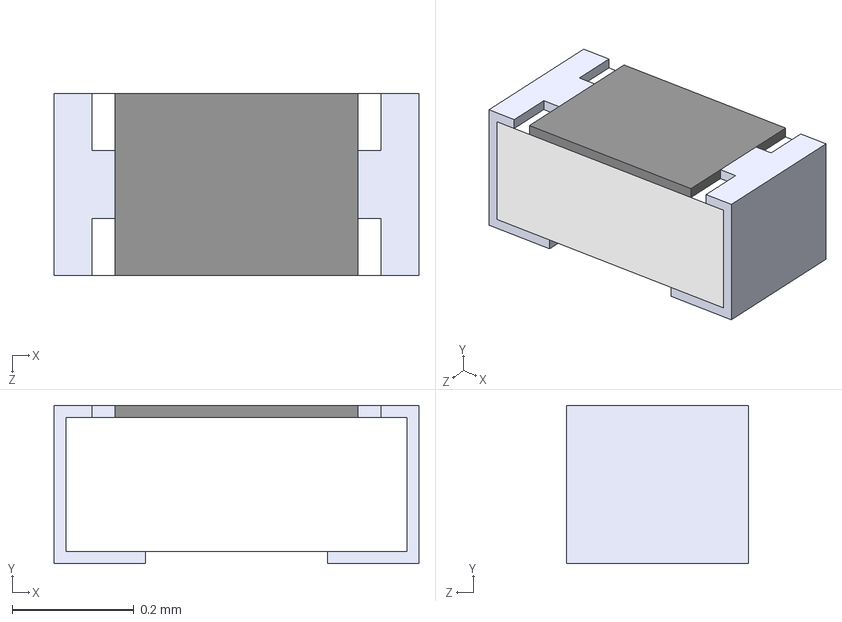
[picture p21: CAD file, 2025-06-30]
Parts/RC0201FR_074K7L/RC0201FR-074K7L.step
0.6 x 0.26 x 0.3 mm

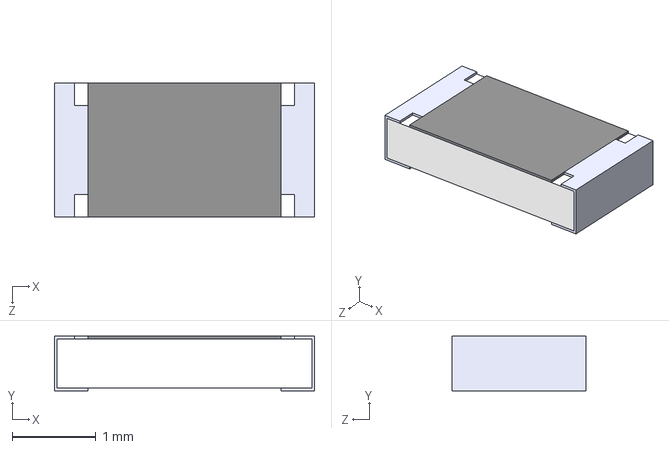
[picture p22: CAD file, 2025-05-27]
Parts/RC1206FR_07120KL/RC1206FR-07120KL.step
3.10 x 0.65 x 1.60 mm

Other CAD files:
Hardware/Complete v3.0/Complete v3.0 3D models/SLDPRT/V3.0.SLDASM
Parts/RMCF0603FT300K/RMCF0603FT300K.step
Parts/RN73H1JTTD5052F50/RN73H1JTTD5052F50.step
Parts/TPS7A0230PDBVR/TPS7A0230PDBVR.stp
Hardware/Charger v1.0/Case_All.SLDPRT
Hardware/Complete v2.0/Complete v2.0 3D models/SLDPRT/ASSEMBLY - COMPLETE.SLDASM
Hardware/Complete v2.0/Complete v2.0 3D models/SLDPRT/Board.SLDPRT
Hardware/Complete v2.0/Complete v2.0 3D models/SLDPRT/Body.SLDPRT
Hardware/Complete v2.0/Complete v2.0 3D models/SLDPRT/Body_Logan.SLDPRT
Hardware/Complete v2.0/Complete v2.0 3D models/SLDPRT/PushPin_spring.SLDPRT
Hardware/Complete v2.0/Complete v2.0 3D models/STEP/Complete v2.0.step
Hardware/Complete v2.0/Complete v2.0 3D models/STL/Back v1.0.STL
Hardware/Complete v2.0/Complete v2.0 3D models/STL/Body v1.0.STL
Hardware/Complete v2.0/Complete v2.0 3D models/STL/PushPin_spring v1.0.STL
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

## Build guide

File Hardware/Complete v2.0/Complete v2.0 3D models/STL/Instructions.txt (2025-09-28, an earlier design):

 Print button, support, pogo support, and back with normal settings

Print everything else with watch setting

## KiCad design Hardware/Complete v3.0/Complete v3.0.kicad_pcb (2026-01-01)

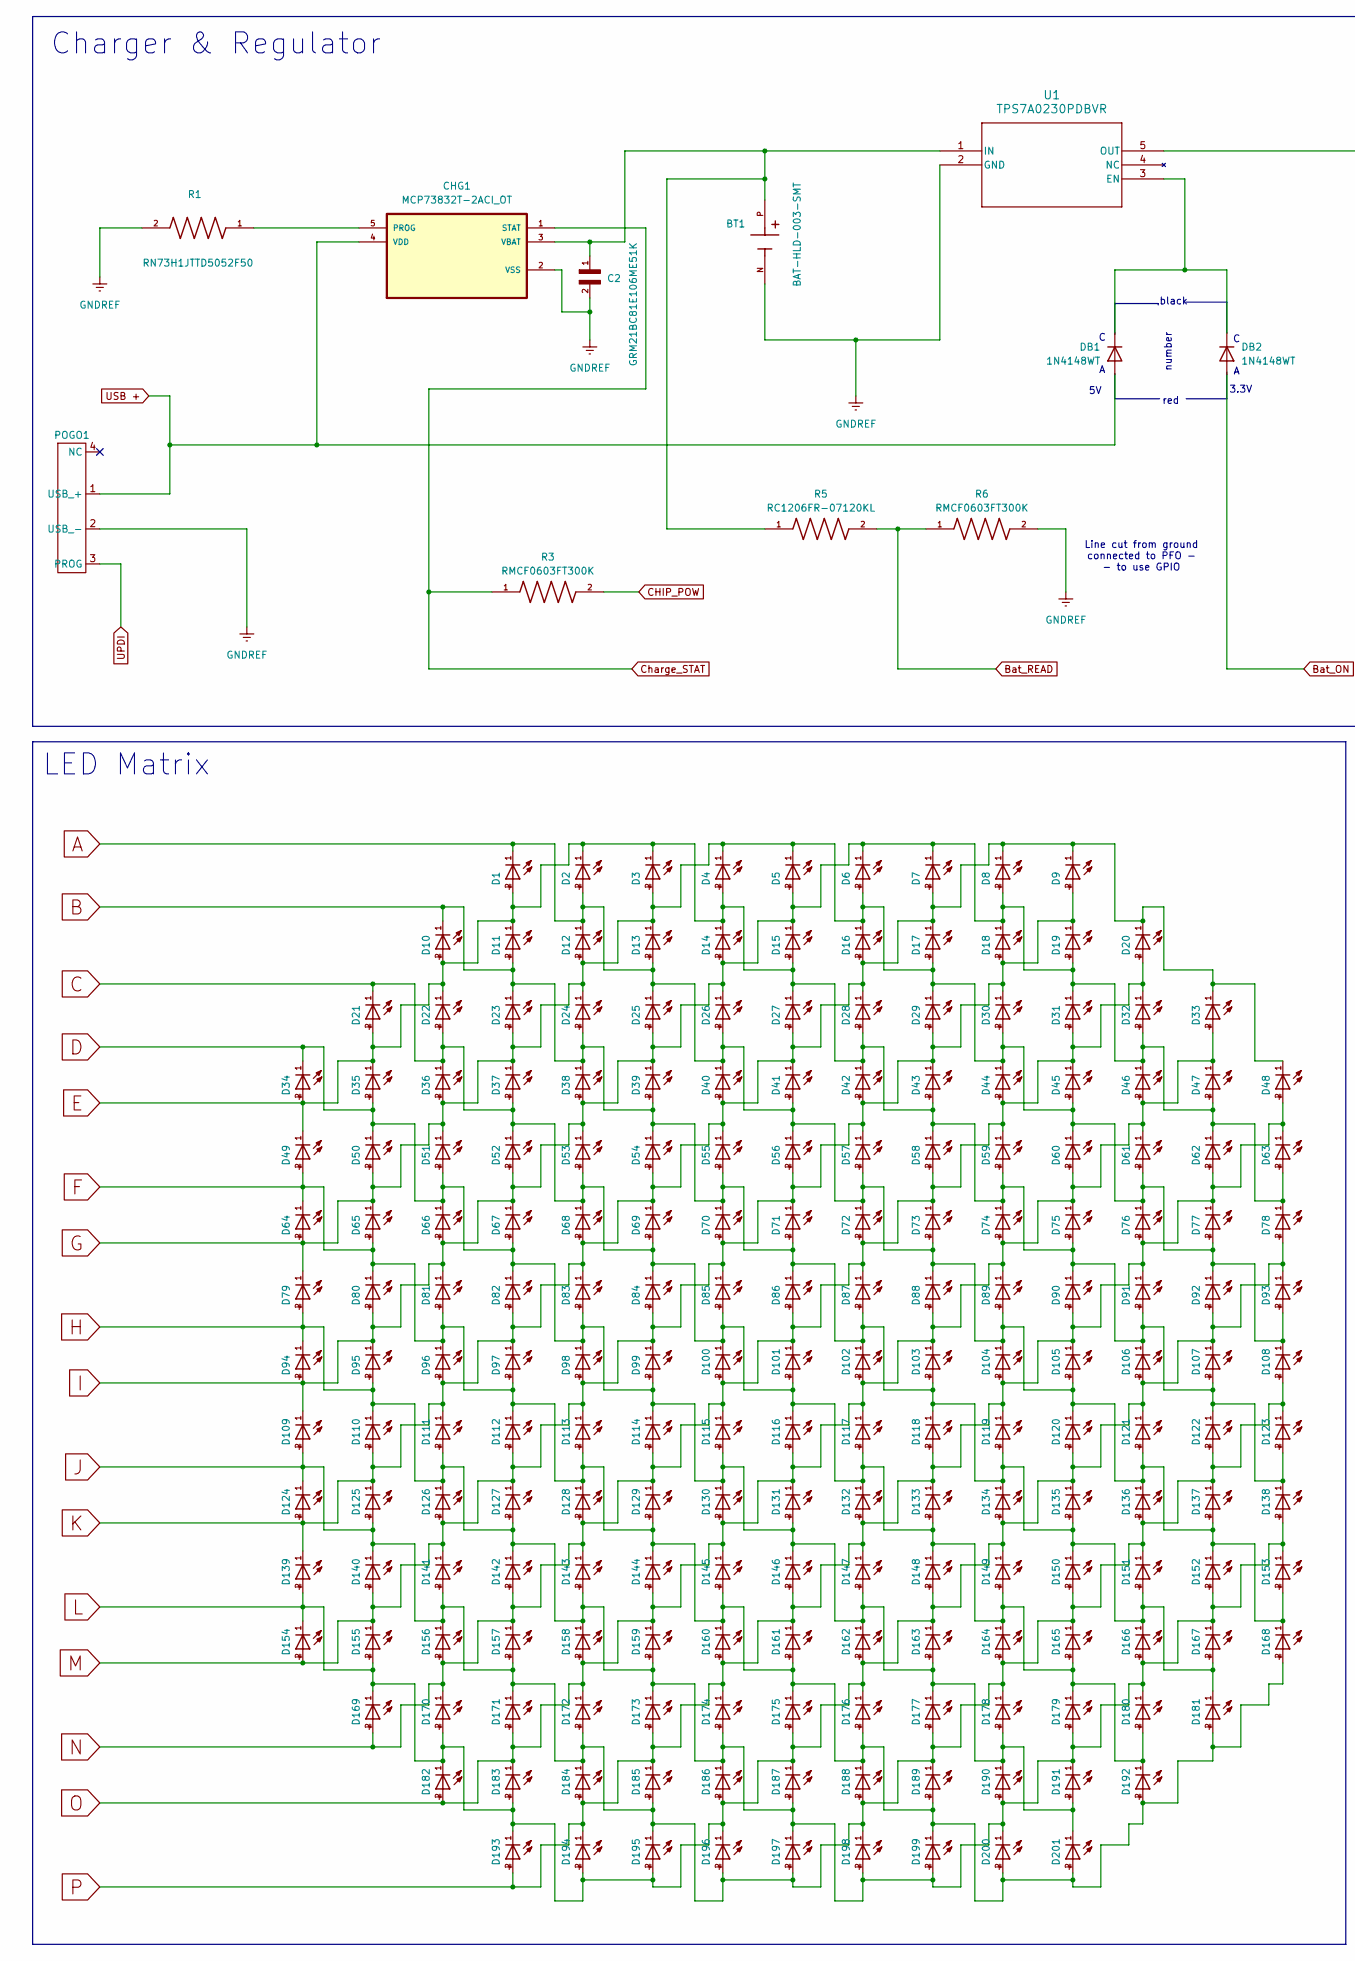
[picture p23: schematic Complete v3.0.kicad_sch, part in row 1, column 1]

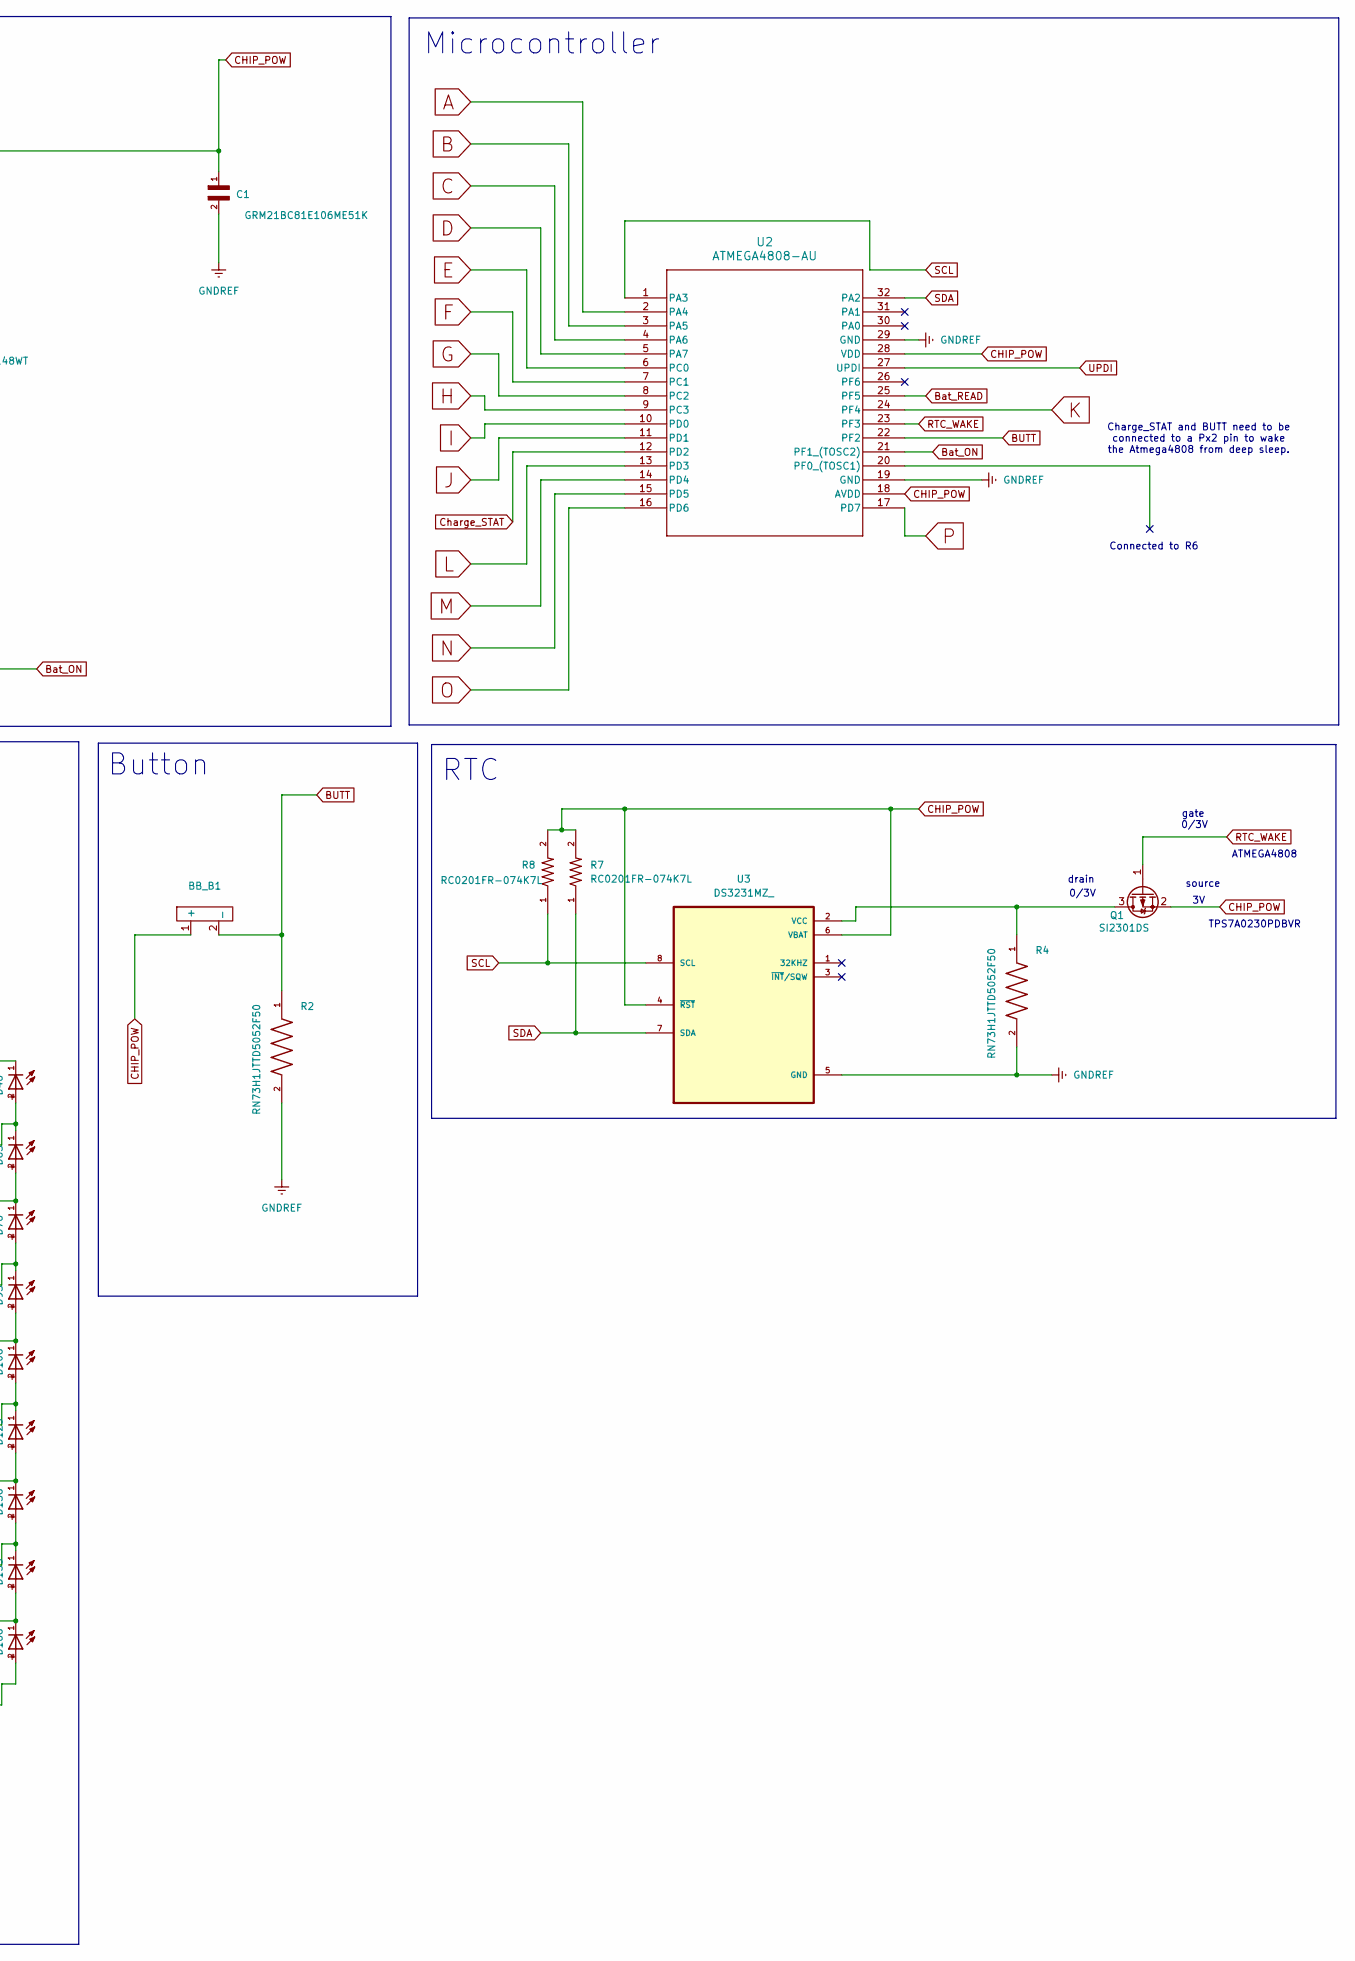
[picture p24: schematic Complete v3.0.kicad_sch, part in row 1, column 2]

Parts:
BB_B1: BB_B
BT1: BAT-HLD-003-SMT; BAT_BAT-HLD-003-SMT_CUT; DigiKey_Part_Number 343-BAT-HLD-003-SMT-ND
C1, C2: GRM21BC81E106ME51K; CAPC2012X140N
CHG1: MCP73832T-2ACI_OT; SOT95P270X145-5N
D1, D2, D3, D4, D5, D6, D7, D8, D9, D10, D11, D12, D13, D14, D15, D16, D17, D18, D19, D20, D21, D22, D23, D24, D25, D26, D27, D28, D29, D30, D31, D32, D33, D34, D35, D36, D37, D38, D39, D40, D41, D42, D43, D44, D45, D46, D47, D48, D49, D50, D51, D52, D53, D54, D55, D56, D57, D58, D59, D60, D61, D62, D63, D64, D65, D66, D67, D68, D69, D70, D71, D72, D73, D74, D75, D76, D77, D78, D79, D80, D81, D82, D83, D84, D85, D86, D87, D88, D89, D90, D91, D92, D93, D94, D95, D96, D97, D98, D99, D100, D101, D102, D103, D104, D105, D106, D107, D108, D109, D110, D111, D112, D113, D114, D115, D116, D117, D118, D119, D120, D121, D122, D123, D124, D125, D126, D127, D128, D129, D130, D131, D132, D133, D134, D135, D136, D137, D138, D139, D140, D141, D142, D143, D144, D145, D146, D147, D148, D149, D150, D151, D152, D153, D154, D155, D156, D157, D158, D159, D160, D161, D162, D163, D164, D165, D166, D167, D168, D169, D170, D171, D172, D173, D174, D175, D176, D177, D178, D179, D180, D181, D182, D183, D184, D185, D186, D187, D188, D189, D190, D191, D192, D193, D194, D195, D196, D197, D198, D199, D200, D201: WL-SMCC_0402
DB1, DB2: 1N4148WT; D_SOD-523
POGO1: Untitled
Q1: SI2301DS; SOT-23
R1, R2, R4: RN73H1JTTD5052F50
R3, R6: RMCF0603FT300K
R5: RC1206FR-07120KL; RC1206FR_07120KL
R7, R8: RC0201FR-074K7L; RESC0603X26N
U1: TPS7A0230PDBVR
U2: ATMEGA4808-AU; TQFP-32_7x7mm_P0.8mm
U3: DS3231MZ_

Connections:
A: D1.1, D2.2, D12.1, D13.2, D25.1, D26.2, D40.1, D41.2, D56.1, D57.2, D72.1, D73.2, D88.1, D89.2, D104.1, D105.2, D120.1, D121.2, D136.1, D137.2, D152.1, D153.2, D168.1, U2.2 (PA4)
B: D10.1, D11.2, D23.1, D24.2, D38.1, D39.2, D54.1, D55.2, D70.1, D71.2, D86.1, D87.2, D102.1, D103.2, D118.1, D119.2, D134.1, D135.2, D150.1, D151.2, D166.1, D167.2, D181.1, U2.3 (PA5)
BUTT: BB_B1.2 (_), R2.1, U2.22 (PF2)
Bat_ON: DB2.2 (A), U2.21 (PF1_(TOSC2))
Bat_READ: R5.2, R6.1, U2.25 (PF5)
C: D21.1, D22.2, D36.1, D37.2, D52.1, D53.2, D68.1, D69.2, D84.1, D85.2, D100.1, D101.2, D116.1, D117.2, D132.1, D133.2, D148.1, D149.2, D164.1, D165.2, D179.1, D180.2, D192.1, U2.4 (PA6)
CHIP_POW: BB_B1.1 (+), C1.1, Q1.2 (S), R3.2, R7.2, R8.2, U1.5 (OUT), U2.18 (AVDD), U2.28 (VDD), U3.4 (~RST), U3.6 (VBAT)
Charge_STAT: CHG1.1 (STAT), R3.1, U2.12 (PD2)
D: D34.1, D35.2, D50.1, D51.2, D66.1, D67.2, D82.1, D83.2, D98.1, D99.2, D114.1, D115.2, D130.1, D131.2, D146.1, D147.2, D162.1, D163.2, D177.1, D178.2, D190.1, D191.2, D201.1, U2.5 (PA7)
E: D1.2, D2.1, D3.1, D4.2, D10.2, D11.1, D14.1, D15.2, D21.2, D22.1, D27.1, D28.2, D34.2, D35.1, D42.1, D43.2, D49.1, D58.1, D59.2, D74.1, D75.2, D90.1, D91.2, D106.1, D107.2, D122.1, D123.2, D138.1, U2.6 (PC0)
F: D49.2, D64.1, D65.2, D80.1, D81.2, D96.1, D97.2, D112.1, D113.2, D128.1, D129.2, D144.1, D145.2, D160.1, D161.2, D168.2, D175.1, D176.2, D181.2, D188.1, D189.2, D192.2, D199.1, D200.2, D201.2, U2.7 (PC1)
G: D3.2, D4.1, D5.1, D6.2, D12.2, D13.1, D16.1, D17.2, D23.2, D24.1, D29.1, D30.2, D36.2, D37.1, D44.1, D45.2, D50.2, D51.1, D60.1, D61.2, D64.2, D65.1, D76.1, D77.2, D79.1, D92.1, D93.2, D108.1, U2.8 (PC2)
GNDREF: BT1.N, C1.2, C2.2, CHG1.2 (VSS), POGO1.2 (USB_-), R1.2, R2.2, R4.2, R6.2, U1.2 (GND), U2.19 (GND), U2.29 (GND), U3.5 (GND)
H: D79.2, D94.1, D95.2, D110.1, D111.2, D126.1, D127.2, D138.2, D142.1, D143.2, D152.2, D153.1, D158.1, D159.2, D166.2, D167.1, D173.1, D174.2, D179.2, D180.1, D186.1, D187.2, D190.2, D191.1, D197.1, D198.2, D199.2, D200.1, U2.9 (PC3)
I: D5.2, D6.1, D7.1, D8.2, D14.2, D15.1, D18.1, D19.2, D25.2, D26.1, D31.1, D32.2, D38.2, D39.1, D46.1, D47.2, D52.2, D53.1, D62.1, D63.2, D66.2, D67.1, D78.1, D80.2, D81.1, D94.2, D95.1, D109.1, U2.10 (PD0)
J: D108.2, D109.2, D122.2, D123.1, D124.1, D125.2, D136.2, D137.1, D140.1, D141.2, D150.2, D151.1, D156.1, D157.2, D164.2, D165.1, D171.1, D172.2, D177.2, D178.1, D184.1, D185.2, D188.2, D189.1, D195.1, D196.2, D197.2, D198.1, U2.11 (PD1)
K: D7.2, D8.1, D9.1, D16.2, D17.1, D20.1, D27.2, D28.1, D33.1, D40.2, D41.1, D48.1, D54.2, D55.1, D68.2, D69.1, D82.2, D83.1, D96.2, D97.1, D110.2, D111.1, D124.2, D125.1, D139.1, U2.24 (PF4)
L: D78.2, D92.2, D93.1, D106.2, D107.1, D120.2, D121.1, D134.2, D135.1, D139.2, D148.2, D149.1, D154.1, D155.2, D162.2, D163.1, D169.1, D170.2, D175.2, D176.1, D182.1, D183.2, D186.2, D187.1, D193.1, D194.2, D195.2, D196.1, U2.13 (PD3)
M: D9.2, D18.2, D19.1, D29.2, D30.1, D42.2, D43.1, D56.2, D57.1, D70.2, D71.1, D84.2, D85.1, D98.2, D99.1, D112.2, D113.1, D126.2, D127.1, D140.2, D141.1, D154.2, D155.1, U2.14 (PD4)
N: D20.2, D31.2, D32.1, D44.2, D45.1, D58.2, D59.1, D72.2, D73.1, D86.2, D87.1, D100.2, D101.1, D114.2, D115.1, D128.2, D129.1, D142.2, D143.1, D156.2, D157.1, D169.2, D170.1, U2.15 (PD5)
unnamed: CHG1.5 (PROG), R1.1
unnamed: BT1.P, C2.1, CHG1.3 (VBAT), R5.1, U1.1 (IN)
unnamed: DB1.1 (K), DB2.1 (K), U1.3 (EN)
unnamed: Q1.3 (D), R4.1, U3.2 (VCC)
O: D33.2, D46.2, D47.1, D60.2, D61.1, D74.2, D75.1, D88.2, D89.1, D102.2, D103.1, D116.2, D117.1, D130.2, D131.1, D144.2, D145.1, D158.2, D159.1, D171.2, D172.1, D182.2, D183.1, U2.16 (PD6)
P: D48.2, D62.2, D63.1, D76.2, D77.1, D90.2, D91.1, D104.2, D105.1, D118.2, D119.1, D132.2, D133.1, D146.2, D147.1, D160.2, D161.1, D173.2, D174.1, D184.2, D185.1, D193.2, D194.1, U2.17 (PD7)
RTC_WAKE: Q1.1 (G), U2.23 (PF3)
SCL: R8.1, U2.1 (PA3), U3.8 (SCL)
SDA: R7.1, U2.32 (PA2), U3.7 (SDA)
UPDI: POGO1.3 (PROG), U2.27 (UPDI)
USB +: CHG1.4 (VDD), DB1.2 (A), POGO1.1 (USB_+)

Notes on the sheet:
Charge_STAT and BUTT need to be connected to a Px2 pin to wake the Atmega4808 from deep sleep.
TPS7A0230PDBVR
Microcontroller
Button
Charger & Regulator
0/3V
ATMEGA4808
Line cut from ground connected to PFO - - to use GPIO
number
3.3V
gate
Connected to R6
drain
black
RTC
LED Matrix
red
source

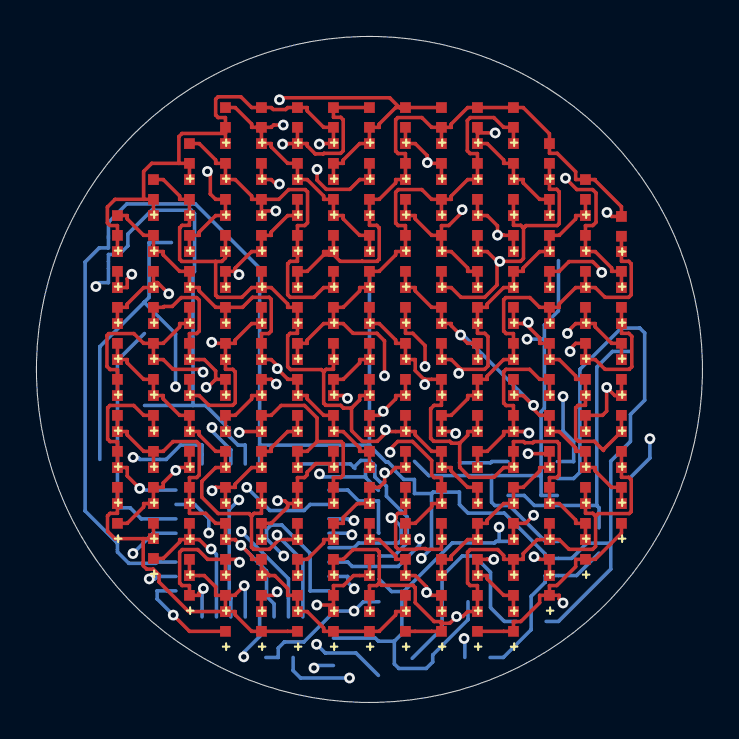
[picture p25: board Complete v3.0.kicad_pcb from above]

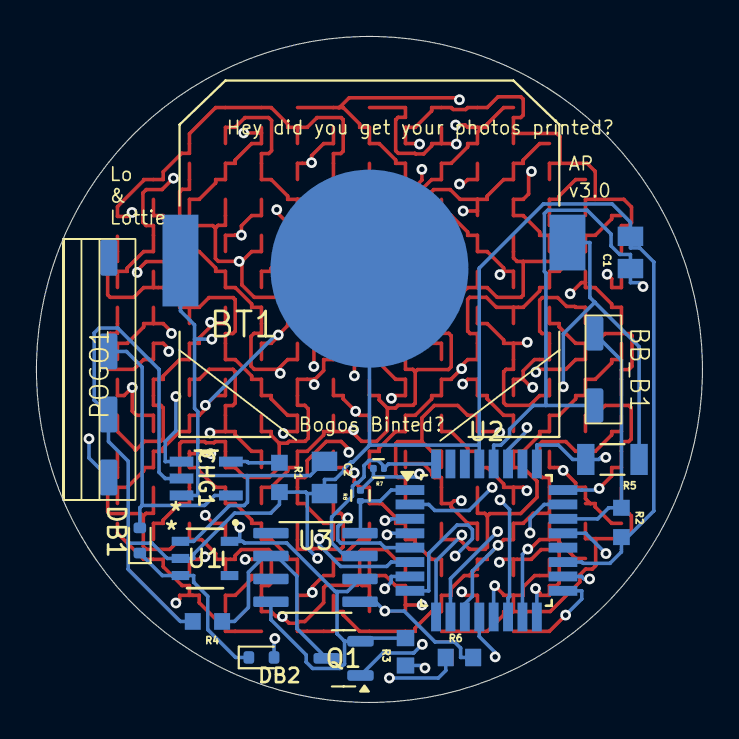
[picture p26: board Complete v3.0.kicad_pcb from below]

Board: 4 copper layers, 37.0 x 37.0 mm, 221 parts (20 on the bottom side), 31 nets.

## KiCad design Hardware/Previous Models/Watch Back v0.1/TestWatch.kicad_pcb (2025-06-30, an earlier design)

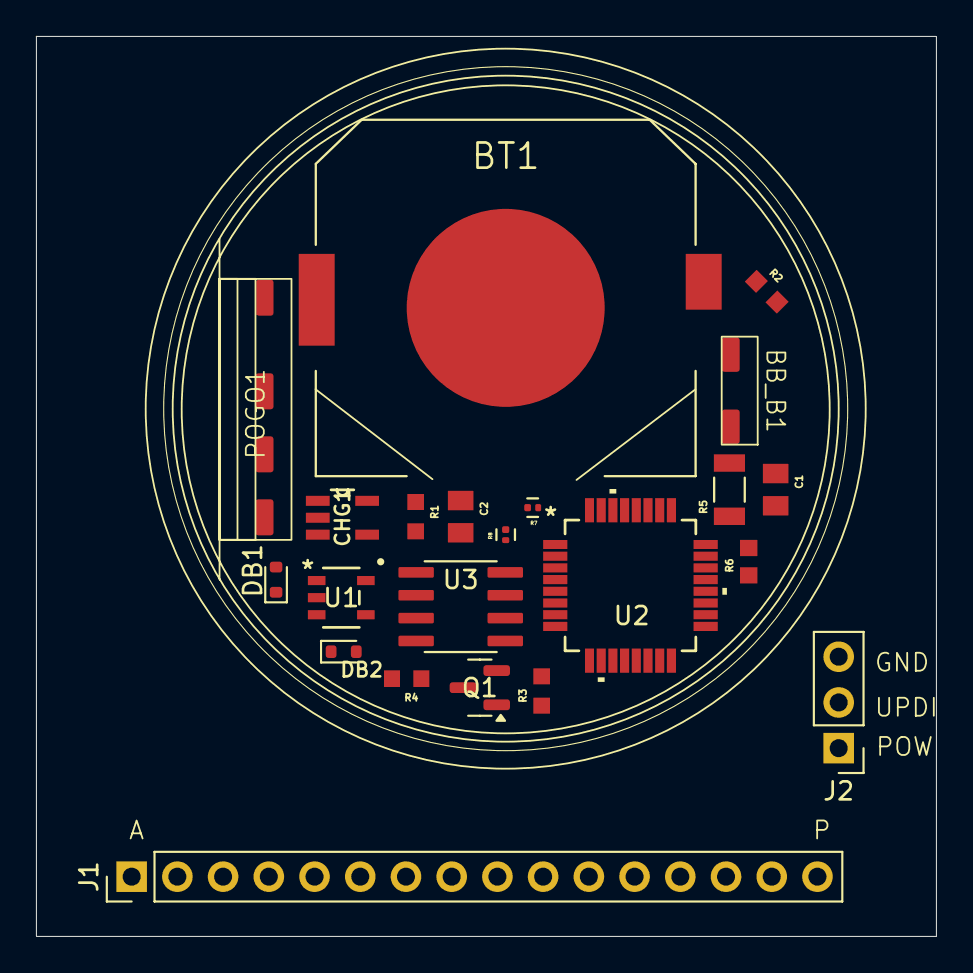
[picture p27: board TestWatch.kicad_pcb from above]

Board: 2 copper layers, 50.0 x 50.0 mm, 22 parts (0 on the bottom side), 31 nets, no tracks yet.

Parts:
BB_B1: BB_B
BT1: BAT-HLD-003-SMT; BAT_BAT-HLD-003-SMT_CUT
C1, C2: GRM21BC81E106ME51K; CAPC2012X140N
CHG1: MCP73832T-2ACI_OT; SOT95P270X145-5N
DB1, DB2: 1N4148WT; D_SOD-523
J1: Conn_01x16; PinHeader_1x16_P2.54mm_Vertical
J2: Conn_01x03; PinHeader_1x03_P2.54mm_Vertical
POGO1: Untitled
Q1: IRLML6402; SOT-23
R1, R2, R3, R4: RN73H1JTTD5052F50
R5: RC1206FR-07120KL; RC1206FR_07120KL
R6: RMCF0603FT300K
R7, R8: RC0201FR-074K7L; RESC0603X26N
U1: TPS7A0230PDBVR
U2: ATMEGA4808-AU
U3: DS3231MZ_

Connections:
A: J1.1, U2.2 (PA4)
B: J1.2, U2.3 (PA5)
BUTT: BB_B1.2 (_), R2.1, U2.31 (PA1)
Bat_ON: DB2.2 (A), U2.26 (PF6)
Bat_READ: R5.2, R6.1, U2.25 (PF5)
C: J1.3, U2.4 (PA6)
CHIP_POW: BB_B1.1 (+), C1.1, J2.1, Q1.2 (S), R3.2, R7.2, R8.2, U1.5 (OUT), U2.18 (AVDD), U2.28 (VDD), U3.4 (~RST), U3.6 (VBAT)
Charge_STAT: CHG1.1 (STAT), R3.1, U2.24 (PF4)
D: J1.4, U2.5 (PA7)
E: J1.5, U2.6 (PC0)
F: J1.6, U2.7 (PC1)
G: J1.7, U2.8 (PC2)
GNDREF: BT1.N, C1.2, C2.2, CHG1.2 (VSS), J2.3, POGO1.2 (USB_-), R1.2, R2.2, R4.2, R6.2, U1.2 (GND), U2.19 (GND), U2.29 (GND), U3.5 (GND)
H: J1.8, U2.9 (PC3)
I: J1.9, U2.10 (PD0)
J: J1.10, U2.11 (PD1)
K: J1.11, U2.12 (PD2)
L: J1.12, U2.13 (PD3)
M: J1.13, U2.14 (PD4)
N: J1.14, U2.15 (PD5)
unnamed: CHG1.5 (PROG), R1.1
unnamed: BT1.P, C2.1, CHG1.3 (VBAT), R5.1, U1.1 (IN)
unnamed: DB1.1 (K), DB2.1 (K), U1.3 (EN)
unnamed: Q1.1 (G), U2.23 (PF3)
O: J1.15, U2.16 (PD6)
P: J1.16, U2.17 (PD7)
RTC_WAKE: Q1.3 (D), R4.1, U3.2 (VCC)
SCL: R8.1, U2.1 (PA3), U3.8 (SCL)
SDA: R7.1, U2.32 (PA2), U3.7 (SDA)
UPDI: J2.2, POGO1.3 (PROG), U2.27 (UPDI)
USB +: CHG1.4 (VDD), DB1.2 (A), POGO1.1 (USB_+)

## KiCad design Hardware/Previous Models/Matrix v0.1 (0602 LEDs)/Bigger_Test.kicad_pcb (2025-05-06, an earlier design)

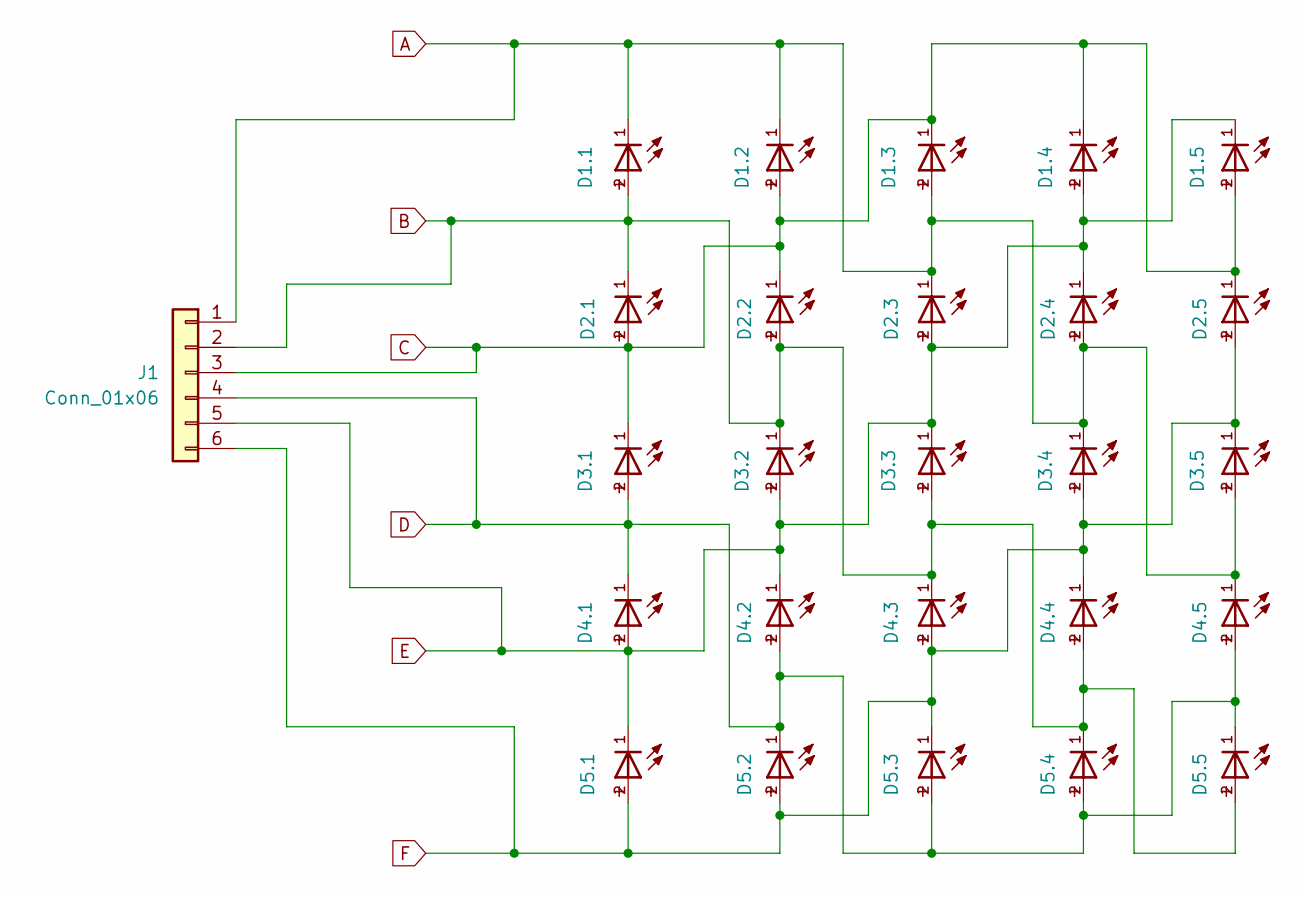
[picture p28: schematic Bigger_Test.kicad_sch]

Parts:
D1.1, D1.2, D1.3, D1.4, D1.5, D2.1, D2.2, D2.3, D2.4, D2.5, D3.1, D3.2, D3.3, D3.4, D3.5, D4.1, D4.2, D4.3, D4.4, D4.5, D5.1, D5.2, D5.3, D5.4, D5.5: WL-SMCW_0603
J1: Conn_01x06

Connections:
A: D1.1.1, D1.2.1, D1.3.2, D2.3.1, D2.4.2, D3.4.1, D3.5.2, D4.5.1, J1.1
B: D1.1.2, D2.1.1, D2.2.2, D3.2.1, D3.3.2, D4.3.1, D4.4.2, D5.4.1, D5.5.2, J1.2
C: D1.2.2, D1.3.1, D1.4.1, D1.5.2, D2.1.2, D2.2.1, D2.5.1, D3.1.1, J1.3
D: D3.1.2, D4.1.1, D4.2.2, D4.5.2, D5.2.1, D5.3.2, D5.4.2, D5.5.1, J1.4
E: D1.4.2, D1.5.1, D2.3.2, D2.4.1, D3.2.2, D3.3.1, D4.1.2, D4.2.1, D5.1.1, J1.5
F: D2.5.2, D3.4.2, D3.5.1, D4.3.2, D4.4.1, D5.1.2, D5.2.2, D5.3.1, J1.6

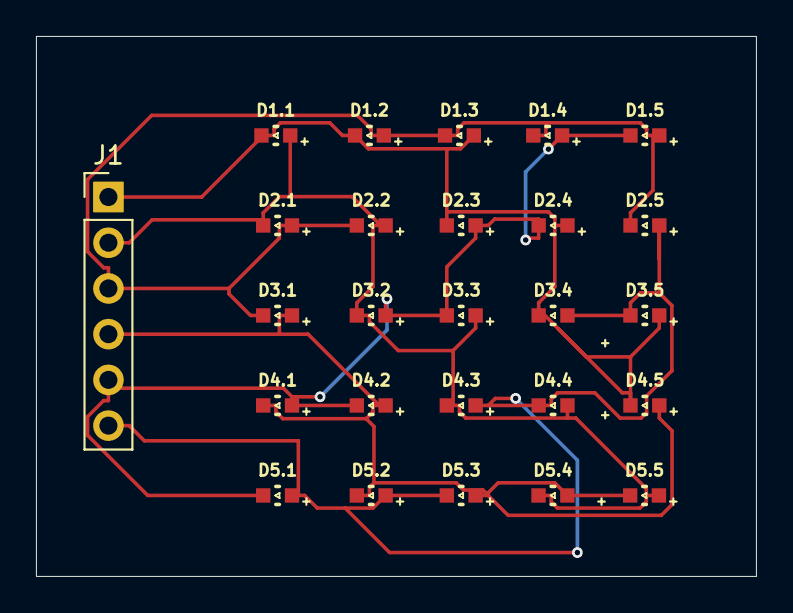
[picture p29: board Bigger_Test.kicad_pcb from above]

Board: 2 copper layers, 40.0 x 30.0 mm, 26 parts (0 on the bottom side), 6 nets.

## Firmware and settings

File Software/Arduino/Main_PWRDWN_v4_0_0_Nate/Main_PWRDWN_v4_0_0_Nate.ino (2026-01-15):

#include <avr/sleep.h>
#include <avr/interrupt.h>
#include "RTClib.h"
#include "WatchData.h"
#include "WatchFunc.h"
#include <string.h>

// === Flags ===
volatile bool wake_flag = false;
volatile bool CHG_flag = false;
volatile bool Minute_flag = false;

// === Battery timing ===
volatile uint8_t sec_count = 0;

// === Pins ===
const int SCL_PIN = 3;
const int Bat_READ_GND = 20;
const int Bat_ON = 21;
const int Button = 22;    // PF2
const int RTC_WAKE = 23;
const int Charge_STAT = 14;
const int Bat_READ = A11; // Pin 25
const int Bat_READ_2 = 26; // Pin 25
const int SDA_PIN = 32;

// === RTC ===
RTC_DS3231 rtc;
DateTime now;

// === Settings ===
int hour = 1;
int minute = 1;
int second = 1;
bool options_mode = false;
bool options_section = true;
int clock_mode = 0;
int wrist_mode = 0;
int LED_flip = 0;
int brightness = 50;
int charge = 1;
int read_timer = 1; 
unsigned long fade_duration = 1000;
unsigned long charge_timer = 1000;

unsigned long time_unplugged = 0;

unsigned long lastBatteryUpdate = 0;
const unsigned long batteryInterval = 60 * 60 * 1000;

int NaN = -1;
int life_start = true;
int press_count = 0;
float volt_cutoff = 2.2 ;

// === Setup ===
void setup() {
  rtc.begin();
  rtc.adjust(DateTime(F(__DATE__), F(__TIME__)));

  pinMode(Bat_READ, INPUT);
  pinMode(Bat_READ_GND, INPUT);
  pinMode(Bat_READ_2, INPUT);

  pinMode(RTC_WAKE, OUTPUT);
  pinMode(RTC_WAKE, HIGH);

  pinMode(Bat_ON, OUTPUT);
  digitalWrite(Bat_ON, HIGH);

  // --- Button interrupt setup (rising edge) ---
  pinMode(Button, INPUT_PULLUP);
  PORTF.PIN2CTRL = PORT_ISC_RISING_gc;
  PORTF.INTFLAGS = PIN2_bm;

  // --- Charger status interrupt (falling edge) ---
  pinMode(Charge_STAT, INPUT_PULLUP);
  PORTD.PIN2CTRL = PORT_ISC_FALLING_gc;
  PORTD.INTFLAGS = PIN2_bm;

  // --- Internal RTC PIT wake every minute (via 1-second PIT counting) ---
  while (RTC.STATUS > 0) {}  // Wait for sync

  // Enable RTC and run in standby; 1-second PIT tick (using 32.768 kHz source)
  RTC.CTRLA = RTC_RUNSTDBY_bm | RTC_PRESCALER_DIV1_gc | RTC_RTCEN_bm;
  RTC.PITCTRLA = RTC_PERIOD_CYC32768_gc | RTC_PITEN_bm;  // 1-second tick
  RTC.PITINTCTRL = RTC_PI_bm;                             // Enable PIT interrupt

  // --- Sleep setup: use power-down mode ---
  set_sleep_mode(SLEEP_MODE_PWR_DOWN);
  SLPCTRL.CTRLA = SLPCTRL_SMODE_PDOWN_gc | SLPCTRL_SEN_bm;

  sei();  // Enable global interrupts
}


// === Main Loop ===
void loop() {

  // --- 1-minute battery reading ---
  if (Minute_flag) {
    Minute_flag = false;


    // Power the divider briefly
    pinMode(Bat_READ_GND, OUTPUT);
    digitalWrite(Bat_READ_GND, LOW);
    delay(50); 


  
    int charge_test = analogRead(Bat_READ);
    float voltage_test = charge_test * (3.0 / 1023.0);  // assuming 3.3V reference
    int charge_percent_test = batteryPercent(voltage_test);
    read_timer = charge_percent_test;


  // ///////////////////////////////////////////// TESTING - TO DISPLAY PERCENTAGE AT TEST /////////////////////////////////////////////
  //   if (voltage_test <= volt_cutoff) {
  //     charge_percent_test = 0;
  //     // digitalWrite(Bat_ON, LOW); // VLM should take vare of it
  //   } else if (voltage_test >= 3.0) {
  //     charge_percent_test = 99;
  //   } else {
  //     charge_percent_test = batteryPercent(voltage_test);
  //   }

  //   if (charge_percent_test < 1) charge_percent_test = 0;

  //   int charge_dig_l_test = charge_percent_test / 10;
  //   int charge_dig_r_test = charge_percent_test % 10;

  //   for (int wait = 0; wait < 50; wait++){
  //     for (uint16_t colCnt = 0; colCnt < large_seg7_matrix[charge_dig_l_test].numElements; colCnt++) {
  //       LED_ON(large_seg7_matrix[charge_dig_l_test].pins[colCnt] - 3, brightness, 100, false);
  //     }
  //     for (uint16_t colCnt = 0; colCnt < large_seg7_matrix[charge_dig_r_test].numElements; colCnt++) {
  //       LED_ON(large_seg7_matrix[charge_dig_r_test].pins[colCnt] + 3, brightness, 100, false);
  //     }
  //   }
    

    
  /////////////////////////////////////////////


    // Remove load from divider
    pinMode(Bat_READ_GND, INPUT);
    delay(50); 

    if (read_timer  <= 3) {
      BYE_flash(0.5, 100, 2);      
      digitalWrite(Bat_ON, LOW); //shuts it off
    }


    delay(50);                         // allow voltage to settle
    digitalWrite(Bat_ON, HIGH); //brings it back when its plugged in, if 

  }

  // --- Wake from charger ---
  if (CHG_flag) {
    CHG_flash(2);
    CHG_flag = false;
    wake_flag = false;
  }

  // --- Wake from button ---
  if (wake_flag) {
    pinMode(RTC_WAKE, LOW);
    delay(50);
    now = rtc.now();
    hour = now.hour();
    minute = now.minute();
    pinMode(RTC_WAKE, HIGH);

    if (hour >= 12) hour -= 12;

    if (clock_mode == 0) {
      Ring_Execute(hour, minute);
    } else {
      Clock_Execute(hour, minute);
    }
    wake_flag = false;
  }

  // --- Options mode ---
  options_mode = Hold_Timer(1000);
  if (options_mode == true) {

    All_flash(0.05, 100, 3);

    // Note: your code uses assignment in the if()s previously; I preserved original logic
    if (options_mode = true) { press_count = -1; Mod_Battery();   options_section = true; }
    if (options_mode = true) { Mod_Brightness(); options_section = true; }
    if (options_mode = true) { Mod_Hour();       options_section = true; }
    if (options_mode = true) { Mod_Minute();     options_section = true; }
    if (options_mode = true) { Mod_ClockMode();  options_section = true; }
    if (options_mode = true) { Mod_WristMode();  options_section = true; }

    options_mode = false;
    All_flash(0.05, 100, 3);
    Crab_Timer(2000);
    delay(50);
    wake_flag = false;
  }

  // === GO TO SLEEP (with BOD disabled for the sleep window) ===
  // Use avr-libc provided macro to correctly disable BOD timing sequence.
  sleep_enable();            // set SE bit
#if defined(sleep_bod_disable)
  sleep_bod_disable();       // safely disable BOD for the upcoming sleep period
#endif
  // Important ordering: enable interrupts then enter sleep so we won't miss an ISR
  sei();
  sleep_cpu();               // execute SLEEP instruction
  sleep_disable();           // clear SE bit after wake
}



// === Button Interrupt (PF2) ===
ISR(PORTF_PORT_vect) {
  if (!(VPORTF.IN & (1 << 2))) return;
  PORTF.INTFLAGS = PIN2_bm;
  wake_flag = true;
}

// === Charger status interrupt (PD2) ===
ISR(PORTD_PORT_vect) {
  if (VPORTD.IN & (1 << 2)) return;
  PORTD.INTFLAGS = PIN2_bm;
  CHG_flag = true;
}

// === Internal RTC PIT interrupt (1-second tick) ===
ISR(RTC_PIT_vect) {
  RTC.PITINTFLAGS = RTC_PI_bm;
  
  sec_count++;
  if (sec_count >= read_timer ) {
    sec_count = 0;
    Minute_flag = true;
  }
}

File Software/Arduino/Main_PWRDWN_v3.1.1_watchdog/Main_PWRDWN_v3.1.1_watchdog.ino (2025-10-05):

#include <avr/sleep.h>
#include <avr/interrupt.h>
#include <avr/wdt.h>
#include "RTClib.h"
#include "WatchData.h"
#include "WatchFunc.h"
#include <string.h>

// === Flags ===
volatile bool wake_flag = false;
volatile bool CHG_flag = false;
volatile bool wdt_flag = false;  // <-- New flag for watchdog wake

// === Pins ===
const int SCL_PIN = 3;
const int Bat_ON = 21;
const int Button = 22;  // PF2 (pin 2 on Arduino pinout — confirm on your board)
const int RTC_WAKE = 23;
const int Charge_STAT = 14;
const int Bat_READ = A11;  // 25
const int SDA_PIN = 32;

// === RTC ===
RTC_DS3231 rtc;
DateTime now;

// === Settings ===
int hour = 1;
int minute = 1;
int second = 1;
bool options_mode = false;
bool options_section = true;
int clock_mode = 0;
int wrist_mode = 0;
int LED_flip = 0;
int brightness = 50;
int charge = 1;
unsigned long fade_duration = 1000;
unsigned long charge_timer = 1000;

unsigned long battery_ticks = 0;          // Counts watchdog cycles (~8s each)
const unsigned long batteryTarget = 450;  // 450×8s ≈ 1 hour

int NaN = -1;
int life_start = true;
int press_count = 0;

void setup() {
  rtc.begin();
  rtc.adjust(DateTime(F(__DATE__), F(__TIME__)));

  pinMode(Bat_READ, INPUT);
  pinMode(RTC_WAKE, OUTPUT);
  digitalWrite(RTC_WAKE, HIGH);

  pinMode(Bat_ON, OUTPUT);
  digitalWrite(Bat_ON, HIGH);

  // --- Button interrupt setup (rising edge) ---
  pinMode(Button, INPUT_PULLUP);        // Button connected to PF2 with pullup
  PORTF.PIN2CTRL = PORT_ISC_RISING_gc;  // Enable interrupt on rising edge
  PORTF.INTFLAGS = PIN2_bm;             // Clear any pending interrupt

  // --- Charger interrupt (falling edge) ---
  pinMode(Charge_STAT, INPUT_PULLUP);
  PORTD.PIN2CTRL = PORT_ISC_FALLING_gc;
  PORTD.INTFLAGS = PIN2_bm;

  // --- Sleep setup ---
  SLPCTRL.CTRLA = SLPCTRL_SMODE_PDOWN_gc | SLPCTRL_SEN_bm;

  // --- Watchdog setup (8s interval) ---
  _PROTECTED_WRITE(WDT.CTRLA, 0);  // Disable first, safe change
  _PROTECTED_WRITE(WDT.CTRLA,
                   WDT_PERIOD_8KCLK_gc |  // 8-second period
                                          //  WDT_ENABLE_bm         | // Enable WDT
                     WDT_WINDOW_OFF_gc);  // Disable window mode
  WDT.STATUS = 0;                         // Clear sync busy flag (safety)
  // WDT.INTCTRL = WDT_INTMODE_bm;  // Enable interrupt mode

  sei();  // Enable global interrupts
}

void loop() {

  // --- Wake from watchdog (~8s cycle) ---
  if (wdt_flag) {
    wdt_flag = false;
    battery_ticks++;
    if (battery_ticks >= batteryTarget) {  // ~1 hour elapsed
      battery_ticks = 0;
      charge = analogRead(Bat_READ);
      float voltage = charge * (3.0 / 1023.0);  // assuming 3.3V reference
      if (voltage <= 2.0) {
        digitalWrite(Bat_ON, LOW);
      }
    }
  }

  // --- Wake from charger ---
  if (CHG_flag) {
    CHG_flag = false;
    CHG_flash(2);
    wake_flag = false;
  }

  // --- Wake from button ---
  if (wake_flag) {
    wake_flag = false;

    pinMode(RTC_WAKE, LOW);  // Power up DS3231
    delay(50);
    now = rtc.now();
    hour = now.hour();
    minute = now.minute();
    pinMode(RTC_WAKE, HIGH);  // Power down DS3231

    if (hour >= 12) hour -= 12;

    if (clock_mode == 0) {
      Ring_Execute(hour, minute);
    } else {
      Clock_Execute(hour, minute);
    }
  }

  options_mode = Hold_Timer(1000);
  if (options_mode == true) {

    All_flash(0.05, 100, 3);

    //////////// Battery module
    if (options_mode = true) {
      press_count = -1;
      Mod_Battery();
      options_section = true;
    }
    //////////// Brightness module
    if (options_mode = true) {
      Mod_Brightness();
      options_section = true;
    }
    //////////// Hour module
    if (options_mode = true) {
      Mod_Hour();
      options_section = true;
    }
    //////////// Minute Module
    if (options_mode = true) {
      Mod_Minute();
      options_section = true;
    }
    ////////// Clocktype Module
    if (options_mode = true) {
      Mod_ClockMode();
      options_section = true;
    }

    ////////// Wristtype Module
    if (options_mode = true) {
      Mod_WristMode();
      options_section = true;
    }

    ////////////// Closes Modules
    options_mode = false;
    All_flash(0.05, 100, 3);

    Crab_Timer(2000);

    delay(50);
  }


 
  // --- Enter power-down ---
  __asm__ __volatile__("sleep");
}

// === Button Interrupt (PF2) ===
ISR(PORTF_PORT_vect) {
  if (!(VPORTF.IN & (1 << 2))) return;  // Only act on rising edge
  PORTF.INTFLAGS = PIN2_bm;             // Clear interrupt flag
  wake_flag = true;
}

// === Charger Interrupt (PD2) ===
ISR(PORTD_PORT_vect) {
  if (VPORTD.IN & (1 << 2)) return;  // Only act on falling edge
  PORTD.INTFLAGS = PIN2_bm;
  CHG_flag = true;
}

// === Watchdog Interrupt ===
ISR(WDT_vect) {
  wdt_flag = true;  // Set flag so loop() can handle it
}

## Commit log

2025-05-06 Initial File Dump
    [Bigger_Test-B_Cu.gbr, Bigger_Test-B_Mask.gbr, Bigger_Test-B_Paste.gbr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]
2025-05-14 Major Udpate 2
    [BAT-HLD-003-SMT.step, Female.SLDPRT, FullGrid Pin Tracker.xlsx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]
2025-05-27 v0.3 sent for fab, v0.4 still in progress
    v0.3 and v0.4 have the same component footprints - that way, I only need to have 1 stencil (if v0.3 works!!!)
    [Assem1.SLDASM, BAS3010A03WE6327HTSA1.step, Case.SLDPRT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]
2025-06-12 STM32 Chip update
    For some reason, for which I don't know, it is impossible to use tri state logic consistently with the STM32G431KBT6. There is, im guessing, parasitic capacitance between Port A and Port B pins that prevent a pin from ever being specified when the other port (same pin #) is high, low, or Z. I tested this out as well with the NUCLEO-G431KB, the commercial dev board for the STM32G431KBT6. I will be focusing on using an ATMEGA 4808 chip instead.
    [Assem1.SLDASM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]
2025-06-30 Complete v0.1 update
    So I learned a lot of things!
    1.) Micro vias and blind vias add a lot of additional manufacturing costs. Avoid them at all costs
    2.) RTC modules can be used with I2C, so I opted for the DS3231
    3.) The use of the UPDI is awesome - so I used an ATMEGA4808 chip. The grounds need to be common, but the Vsup does not! Tested, and works. Means one less trace/connection of the board (and one less diode).
    4.) PCBWAY requires a minimum pad clearance of 0.22mm for black solder masks. Had to learn how to make custom design rules in KiCad.
    5.) There's more, but those are the biggest this udpate.
    [ATMEGA4808-AU.step, Assem1.SLDASM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]
2025-08-06 Complete v2.0 update
    Skipped over the v1.0 update as the v1.0 was board is the exact same as the v2.0 board, except for one footprint change.
    1.) I have found an inconsistency in one of the footprints and models located on Digikey pertaining to ATMEGA4808-AF. The Ultra Librarian model and footprint do not match the 32TQFP footprint represented in the datasheet. The footprint and model available from Ultra Librarian appears to be too small.
    2.) After reviewing the Atmega4808 datasheet, I now know that no all pins have the functionality to wake the microcontroller from deep sleep mode. Idle mode allows for all pins to wake up the device using the RISING condition, while Deep Sleep mode only a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
    [ASSEMBLY - COMPLETE.SLDASM, Assem1.SLDASM, B3U-1100P.step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]
2025-08-08 Software v1.0 update
    - Added two clock modes:
    • PING: a sonar ping unveils the hour (inner dot) and minute (outer dot)
    • 4DIG: just 4 digits (HHMM) displaying time.
    - Added a charge indicator when the magnetic charger is plugged in
    - Added all the options modules:
    • Battery life indicator
    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
    [Complete v2.0.kicad_pcb, Pulse behavior.xlsx]
2025-08-11 Software v1.1 Update
    - Made a python GUI to easily create LED patterns on watch using buttons. Easy for copy/paste into Arduino
    - Crab
    [Complete v2.0 Component Review.xlsx, Pulse behavior.xlsx]
2025-08-11 Software v1.1 Update
    Software v1.1 Update
    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
2025-09-28 Update - V3.0
    I lied. I said I was going to stop working on hardware and only focus on software. But something was bothering me. The two mistakes in version 2.0 were: one of the pins was always high (no idea) and two, the charge sense pin was NOT on an asynchronous pin - meaning the watch wouldn't know it was charging (it was charging, but it didn't know), until a button was pressed. Now, in V3.0, the the charge sense is routed to an asynchronous pin, so when it's plugged in it can show can indicator automatically (with no button press)! I also got rid of the nuts on the back to screw in the backplate and went for a compression fitting - it looks a lot cleaner and more components can be acce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
    [ASSEMBLY - COMPLETE.SLDASM, B3U-1100P.step, Back.SLDPRT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]
2025-09-30 Version 3 software update
    • set the BOD to 2.6V (dont go higher than that)
    • Added charger wake flag
    • Added charger indicator
    • Set the software version number to match the hardware number
    [Complete v2.0 Component Review.xlsx, Complete v3.0.kicad_pcb, Complete v3.0.kicad_sch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]
2025-10-05 Version 3 - Software update
    - Added increased battery protection (with watchdog timer)
    - Added John Conway's Game of Life as an easter egg
2025-10-15 Trying to add battery saver module
    work in progress
2025-11-09 Near Final Update
    Found out the BOD controller only shuts down the chip control instead of shutting down the functionality of the pins. I have rewrote the software to use a different control function (VLM instead of B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
    Additionally, I re-wired 2 traces on the circuit board so that the battery-percentage module is 100% safe and will not drain the battery. It's not worth paying the money to get new boards printed, si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
    This needs to be tested, of course.
    [Complete v3.0.kicad_pcb, Complete v3.0.kicad_sch]
2026-01-01 Last Update - Part 1
    Well, this project is coming to an end. I have found a way to safely shut down the watch - by checking the battery voltage by intervals of seconds * previous battery percentage. That way, 99% will ha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
    [Complete v2.0 Component Review.xlsx, Complete v3.0.kicad_pcb]
